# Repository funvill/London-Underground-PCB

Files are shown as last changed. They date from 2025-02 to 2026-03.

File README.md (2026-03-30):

# London-Underground-PCB

A decorative PCB with 600 individually addressable RGB LEDs arranged in the London Underground map layout. Animated trains travel along each tube line using official TfL line colors.

[PCB Preview](https://kicanvas.org/?github=https://github.com/funvill/London-Underground-PCB/tree/main/hardware) via kicanvas

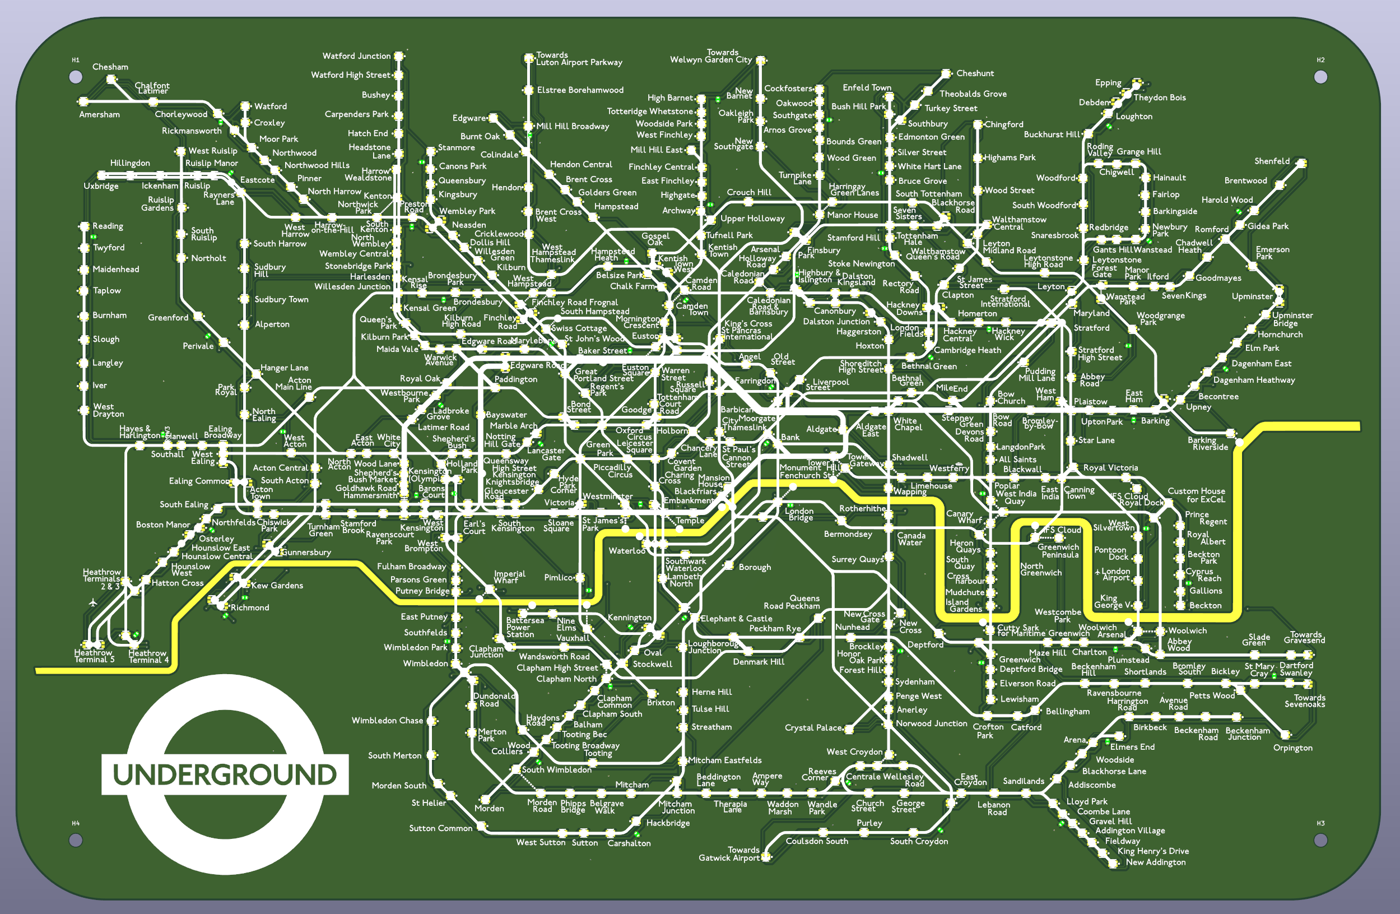
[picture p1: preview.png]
Preview


## Documentation

- [docs.md](docs.md) — Full project documentation (hardware specs, firmware guide, station mapping)
- [CHANGELOG.md](CHANGELOG.md) — Version history for firmware and hardware
- [CLAUDE.md](CLAUDE.md) — Guide for AI assistants making changes to this project

## Versions

- **Hardware:** v2025-Nov-30
- **Firmware:** v1.0.0

## Related

See [Washington Metro PCB](https://github.com/funvill/washington-metro-pcb) for a previous example.

Made by: [Steven (@funvill)](https://blog.abluestar.com/about)

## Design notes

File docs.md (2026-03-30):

# London Underground PCB — Project Documentation

> This document is updated alongside firmware and hardware changes. See [CHANGELOG.md](CHANGELOG.md) for version history.

---

## What is this?

A decorative PCB shaped like the London Underground map with 600 individually addressable RGB LEDs — one per station. The firmware animates "trains" travelling along each tube line in real time, using the correct line colors from the official TfL palette.

The board is powered and controlled by a **Seeed Studio XIAO ESP32C3** microcontroller soldered directly onto the PCB.

Preview

[View PCB in browser (KiCanvas)](https://kicanvas.org/?github=https://github.com/funvill/London-Underground-PCB/tree/main/hardware)

Related project: [Washington Metro PCB](https://github.com/funvill/washington-metro-pcb)

Made by: [Steven (@funvill)](https://blog.abluestar.com/about)

---

## Hardware

### Current Version: v2025-Nov-30

Manufactured by JLCPCB, November 2025.

### Specifications

| Item | Value |
|---|---|
| LEDs | 600× WS2812B (XL-1615RGBC, 1.6×1.5mm) |
| Microcontroller | Seeed Studio XIAO ESP32C3 |
| LED data pin | D7 |
| Power input | USB-C (via XIAO board) |
| LED color order | GRB |
| PCB design tool | KiCAD 7 |

### Components (JLCPCB Part Numbers)

| Component | Description | Part # |
|---|---|---|
| WS2812B LED | 1.6×1.5mm RGB addressable | C5349954 |
| Button | SMD 4-pin 5.1×5.1mm | C318884 |
| Resistor | 0Ω 1206 | C17888 |

### Tube Lines on the Board

| Line | Color (RGB) | Stations |
|---|---|---|
| Bakerloo | (120, 70, 0) brown | 25 |
| Central | Red | 45 |
| Circle | Yellow | 27 |
| District | Green | 49 |
| Hammersmith & City | Pink | 18 |
| Jubilee | White | 27 |
| Metropolitan | Purple | 31 |
| Northern | (50, 50, 50) dark gray | 50 |
| Piccadilly | Blue | 51 |
| Victoria | Light Blue | 16 |
| Waterloo & City | (0, 180, 160) teal | 2 |
| DLR | (0, 220, 140) light green | 38 |
| London Overground | Orange | 15 |
| Elizabeth line | (130, 0, 200) purple | 40 |
| London Trams | (0, 200, 60) green | varies |

### Known Hardware Issues (v2025-Nov-30)

See `Issues with version 2025-Nov-30.txt` for the full list of 31 identified issues. Key items:

**Missing LEDs — stations with no physical LED on this board revision:**
- Bow Road
- Monument
- Barbican
- Cannon Street
- Eastcote
- Euston Square
- High Street Kensington
- South Hampstead
- (plus Iver, Taplow, Maidenhead, Hillingdon, Herne Hill, and others)

**Assembly issues:**
- ESP32C3 pads too small for easy hand-soldering (extend pads 2mm in next revision)
- USB-C cable protrudes past board edge, making flush mounting difficult
- Need more GND test points on back of board
- XIAO pin numbers (e.g. D7) not silkscreened on PCB

**Labeling errors:**
- "Acton Town" label appears on both LED 14 and LED 65
- "Edgware Road" has two different locations (LED 134 vs LED 94)
- LED 101–104 location unknown
- "Colliers Wood" label reversed
- LED 480 is an arrow, not a station
- LED 482 "Gallions" should be "Gallions Reach"; "Cyprus Reach" should be "Cyprus"
- LED 552 labeled "Grants Hill" should be "Wanstead" (labels swapped)

---

## Firmware

### Current Version: v1.0.0

### Building & Flashing

Requirements: [PlatformIO](https://platformio.org/) with the `espressif32` platform.

```bash
cd firmware/Londonmap
pio run                   # compile
pio run --target upload   # flash over USB
pio device monitor        # serial monitor (115200 baud)
```

On boot the board prints:
```
London Underground PCB
https://github.com/funvill/London-Underground-PCB
Lines configured: 15
```

### Current Mode: Test Mode

The firmware currently runs **TestEachLine** mode to help verify the physical LED-to-station mapping. This is active while the mapping in `stations.h` / `lines.h` is being corrected.

Test mode behavior:
1. All stations on the active line illuminate **green**
2. A single **red** LED sweeps from the first station to the last (200 ms per step)
3. After 3 complete passes, the next line becomes active
4. After all 15 lines have been tested, the sequence repeats

Production animation mode (trains moving and fading) is implemented in `main.cpp` but disabled by a `return;` statement. Once the station mappings are verified, remove that `return;` to enable it.

### Source File Overview

| File | Role |
|---|---|
| `version.h` | Version macros — update every change |
| `stations.h` | `const uint16 STATION_NAME = LED_INDEX;` for all 570+ stations |
| `lines.h` | Ordered station sequences per line (`LINE_BAKERLOO[]`, etc.) |
| `line_config.h` | Hardware defines, `LineDef` struct, `kLines[]` table |
| `main.cpp` | `setup()`, `loop()`, test and animation logic |

### Station Mapping

Every station is a named constant in `stations.h`:

```cpp
const uint16 OXFORD_CIRCUS = 230;
const uint16 UNMAPPED_LED  = 0xFFFF;  // station exists but no LED on board
```

Stations that share a physical LED (interchange stations with a single dot on the map) use lettered suffixes:

```cpp
const uint16 BAKER_STREET_A = 116;  // Bakerloo/Jubilee platform
const uint16 BAKER_STREET_B = 117;  // Circle/Metropolitan platform
```

Lines reference these constants in order (direction doesn't matter — trains run both ways):

```cpp
const uint16 LINE_BAKERLOO[] = {
    ELEPHANT_CASTLE_A,
    LAMBETH_NORTH,
    WATERLOO_A,
    // ... 22 more stations ...
    HARROW_WEALDSTONE
};
```

### Adding or Fixing a Station Mapping

1. Edit the `const uint16 STATION_NAME = NEW_INDEX;` line in `stations.h`
2. If the station is on multiple lines, check all references in `lines.h`
3. Bump `VERSION_PATCH` in `version.h`
4. Add a `CHANGELOG.md` entry under `[Unreleased]`

### Adding a New Line

1. Add a `const uint16 LINE_NEW_NAME[]` array to `lines.h`
2. Add a `LineDef` entry to `kLines[]` in `line_config.h` (name, array pointer, color, speed)
3. Bump `VERSION_MINOR` in `version.h`
4. Document in `CHANGELOG.md`

---

## Station Mapping Reference Files

These files in the project root are **first-pass drafts with known errors**:

| File | Description |
|---|---|
| `station-names-to-led.csv` | Station name → LED index (first attempt, needs correction) |
| `stations-to-leds.txt` | Line name → comma-separated LED list (first attempt, needs correction) |

The **authoritative** mapping lives in `firmware/Londonmap/src/stations.h` and `lines.h`. Update those files, not the CSVs/TXTs.

`london_metro_stations_master_list.md` is the canonical list of all TfL stations. Use it as a reference when verifying or correcting mappings.

---

## Design Files

The `design/` folder contains Affinity Designer source files (`.afdesign`) and SVG/PNG exports used to generate the PCB silkscreen graphics. The London Underground map graphic was adapted into the PCB layout.

---

## Repository Files Quick Reference

| File / Folder | Purpose |
|---|---|
| `README.md` | Project intro and links |
| `CLAUDE.md` | AI assistant guide for making changes |
| `docs.md` | This file — full project documentation |
| `CHANGELOG.md` | Version history |
| `firmware/` | PlatformIO firmware source |
| `hardware/` | KiCAD PCB design |
| `design/` | Affinity Designer graphics |
| `preview.png` | Board render |
| `london_metro_stations_master_list.md` | Canonical station list |
| `station-names-to-led.csv` | Draft mapping (WIP, has errors) |
| `stations-to-leds.txt` | Draft line sequences (WIP, has errors) |
| `Issues with version 2025-Nov-30.txt` | Known hardware issues |

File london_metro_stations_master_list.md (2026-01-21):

# London Metro System – Complete Station List

This document lists **all passenger stations** in the London metro system, defined as **all TfL-operated urban rail services**.

**Included**
- London Underground (Tube)
- Docklands Light Railway (DLR)
- London Overground
- Elizabeth line
- London Trams (Tramlink)

**Excluded**
- National Rail–only stations outside TfL branding
- Freight-only or heritage railways

---

## London Underground (Tube)

### Bakerloo Line
- Elephant & Castle
- Lambeth North
- Waterloo
- Embankment
- Charing Cross
- Piccadilly Circus
- Oxford Circus
- Regent’s Park
- Baker Street
- Marylebone
- Edgware Road
- Paddington
- Warwick Avenue
- Maida Vale
- Kilburn Park
- Queen’s Park
- Kensal Green
- Willesden Junction
- Harlesden
- Stonebridge Park
- Wembley Central
- North Wembley
- South Kenton
- Kenton
- Harrow & Wealdstone

### Central Line
- West Ruislip
- Ruislip Gardens
- South Ruislip
- Northolt
- Greenford
- Perivale
- Hanger Lane
- North Acton
- East Acton
- White City
- Shepherd’s Bush
- Holland Park
- Notting Hill Gate
- Queensway
- Lancaster Gate
- Marble Arch
- Bond Street
- Oxford Circus
- Tottenham Court Road
- Holborn
- Chancery Lane
- St Paul’s
- Bank
- Liverpool Street
- Bethnal Green
- Mile End
- Stratford
- Leyton
- Leytonstone
- Wanstead
- Redbridge
- Gants Hill
- Newbury Park
- Barkingside
- Fairlop
- Hainault
- Grange Hill
- Chigwell
- Roding Valley
- Woodford
- Buckhurst Hill
- Loughton
- Debden
- Theydon Bois
- Epping

### Circle Line
- Paddington
- Edgware Road
- Baker Street
- Great Portland Street
- Euston Square
- King’s Cross St Pancras
- Farringdon
- Barbican
- Moorgate
- Liverpool Street
- Aldgate
- Tower Hill
- Monument
- Cannon Street
- Mansion House
- Blackfriars
- Temple
- Embankment
- Westminster
- St James’s Park
- Victoria
- Sloane Square
- South Kensington
- Gloucester Road
- High Street Kensington
- Notting Hill Gate
- Bayswater

### District Line
- Upminster
- Upminster Bridge
- Hornchurch
- Elm Park
- Dagenham East
- Dagenham Heathway
- Becontree
- Upney
- Barking
- East Ham
- Upton Park
- Plaistow
- West Ham
- Bromley-by-Bow
- Bow Road
- Mile End
- Stepney Green
- Whitechapel
- Aldgate East
- Tower Hill
- Monument
- Cannon Street
- Mansion House
- Blackfriars
- Temple
- Embankment
- Westminster
- St James’s Park
- Victoria
- Sloane Square
- South Kensington
- Gloucester Road
- Earl’s Court
- Kensington (Olympia)
- West Brompton
- Fulham Broadway
- Parsons Green
- Putney Bridge
- East Putney
- Southfields
- Wimbledon Park
- Wimbledon
- Turnham Green
- Gunnersbury
- Kew Gardens
- Richmond
- Acton Town
- Ealing Common
- Ealing Broadway

### Hammersmith & City Line
- Hammersmith
- Goldhawk Road
- Shepherd’s Bush Market
- Wood Lane
- Latimer Road
- Ladbroke Grove
- Westbourne Park
- Paddington
- Edgware Road
- Baker Street
- Great Portland Street
- Euston Square
- King’s Cross St Pancras
- Farringdon
- Barbican
- Moorgate
- Liverpool Street
- Whitechapel
- Barking

### Jubilee Line
- Stanmore
- Canons Park
- Queensbury
- Kingsbury
- Wembley Park
- Neasden
- Dollis Hill
- Willesden Green
- Kilburn
- West Hampstead
- Finchley Road
- Swiss Cottage
- St John’s Wood
- Baker Street
- Bond Street
- Green Park
- Westminster
- Waterloo
- Southwark
- London Bridge
- Bermondsey
- Canada Water
- Canary Wharf
- North Greenwich
- Canning Town
- West Ham
- Stratford

### Metropolitan Line
- Aldgate
- Liverpool Street
- Moorgate
- Barbican
- Farringdon
- King’s Cross St Pancras
- Euston Square
- Great Portland Street
- Baker Street
- Finchley Road
- Wembley Park
- Preston Road
- Northwick Park
- Harrow-on-the-Hill
- North Harrow
- Pinner
- Northwood Hills
- Northwood
- Moor Park
- Rickmansworth
- Chorleywood
- Chalfont & Latimer
- Chesham
- Amersham
- Watford
- Croxley
- Uxbridge
- Ickenham
- Ruislip
- Ruislip Manor
- Eastcote
- Rayners Lane

### Northern Line
- Battersea Power Station
- Nine Elms
- Kennington
- Waterloo
- Embankment
- Charing Cross
- Leicester Square
- Tottenham Court Road
- Goodge Street
- Warren Street
- Euston
- Camden Town
- Chalk Farm
- Belsize Park
- Hampstead
- Golders Green
- Brent Cross
- Hendon Central
- Colindale
- Burnt Oak
- Edgware
- Mornington Crescent
- Kentish Town
- Tufnell Park
- Archway
- Highgate
- East Finchley
- Finchley Central
- West Finchley
- Woodside Park
- Totteridge & Whetstone
- High Barnet
- Mill Hill East
- Oval
- Stockwell
- Clapham North
- Clapham Common
- Clapham South
- Balham
- Tooting Bec
- Tooting Broadway
- Colliers Wood
- South Wimbledon
- Morden

### Piccadilly Line
- Cockfosters
- Oakwood
- Southgate
- Arnos Grove
- Bounds Green
- Wood Green
- Turnpike Lane
- Manor House
- Finsbury Park
- Arsenal
- Holloway Road
- Caledonian Road
- King’s Cross St Pancras
- Russell Square
- Holborn
- Covent Garden
- Leicester Square
- Piccadilly Circus
- Green Park
- Hyde Park Corner
- Knightsbridge
- South Kensington
- Gloucester Road
- Earl’s Court
- Barons Court
- Hammersmith
- Acton Town
- South Ealing
- Northfields
- Boston Manor
- Osterley
- Hounslow East
- Hounslow Central
- Hounslow West
- Hatton Cross
- Heathrow Terminals 2 & 3
- Heathrow Terminal 4
- Heathrow Terminal 5
- Ealing Common
- North Ealing
- Park Royal
- Alperton
- Sudbury Town
- Sudbury Hill
- South Harrow
- Rayners Lane
- Eastcote
- Ruislip Manor
- Ruislip
- Ickenham
- Uxbridge

### Victoria Line
- Walthamstow Central
- Blackhorse Road
- Tottenham Hale
- Seven Sisters
- Finsbury Park
- Highbury & Islington
- King’s Cross St Pancras
- Euston
- Warren Street
- Oxford Circus
- Green Park
- Victoria
- Pimlico
- Vauxhall
- Stockwell
- Brixton

### Waterloo & City Line
- Waterloo
- Bank

---

## Docklands Light Railway (DLR)
- Bank
- Tower Gateway
- Shadwell
- Limehouse
- Westferry
- Poplar
- Blackwall
- East India
- Canning Town
- Royal Victoria
- Custom House
- Prince Regent
- Royal Albert
- Beckton Park
- Cyprus
- Gallions Reach
- Beckton
- West Silvertown
- Pontoon Dock
- London City Airport
- King George V
- Woolwich Arsenal
- Stratford
- Stratford International
- Pudding Mill Lane
- Bow Church
- Devons Road
- Langdon Park
- All Saints
- Cutty Sark for Maritime Greenwich
- Greenwich
- Deptford Bridge
- Elverson Road
- Lewisham
- Stratford High Street
- Abbey Road
- West Ham

---

## London Overground
*(Grouped by network; full enumeration retained)*

- Richmond
- Clapham Junction
- Shepherd’s Bush
- Willesden Junction
- Camden Road
- Highbury & Islington
- Stratford
- Barking
- Gospel Oak
- Hackney Central
- Canada Water
- New Cross
- Crystal Palace
- West Croydon
- Watford Junction

---

## Elizabeth line
- Reading
- Twyford
- Maidenhead
- Taplow
- Burnham
- Slough
- Langley
- Iver
- West Drayton
- Hayes & Harlington
- Southall
- Hanwell
- West Ealing
- Ealing Broadway
- Acton Main Line
- Paddington
- Tottenham Court Road
- Farringdon
- Liverpool Street
- Whitechapel
- Canary Wharf
- Custom House
- Woolwich
- Abbey Wood
- Stratford
- Maryland
- Forest Gate
- Manor Park
- Ilford
- Seven Kings
- Goodmayes
- Chadwell Heath
- Romford
- Gidea Park
- Harold Wood
- Brentwood
- Shenfield
- Heathrow Terminals 2 & 3
- Heathrow Terminal 4
- Heathrow Terminal 5

---

## London Trams (Tramlink)
- Wimbledon
- Mitcham Junction
- East Croydon
- West Croydon
- Beckenham Junction
- New Addington
- Elmers End

---

*Document purpose: canonical human-readable reference list. Machine-normalized CSV and NaPTAN-keyed datasets maintained separately.*

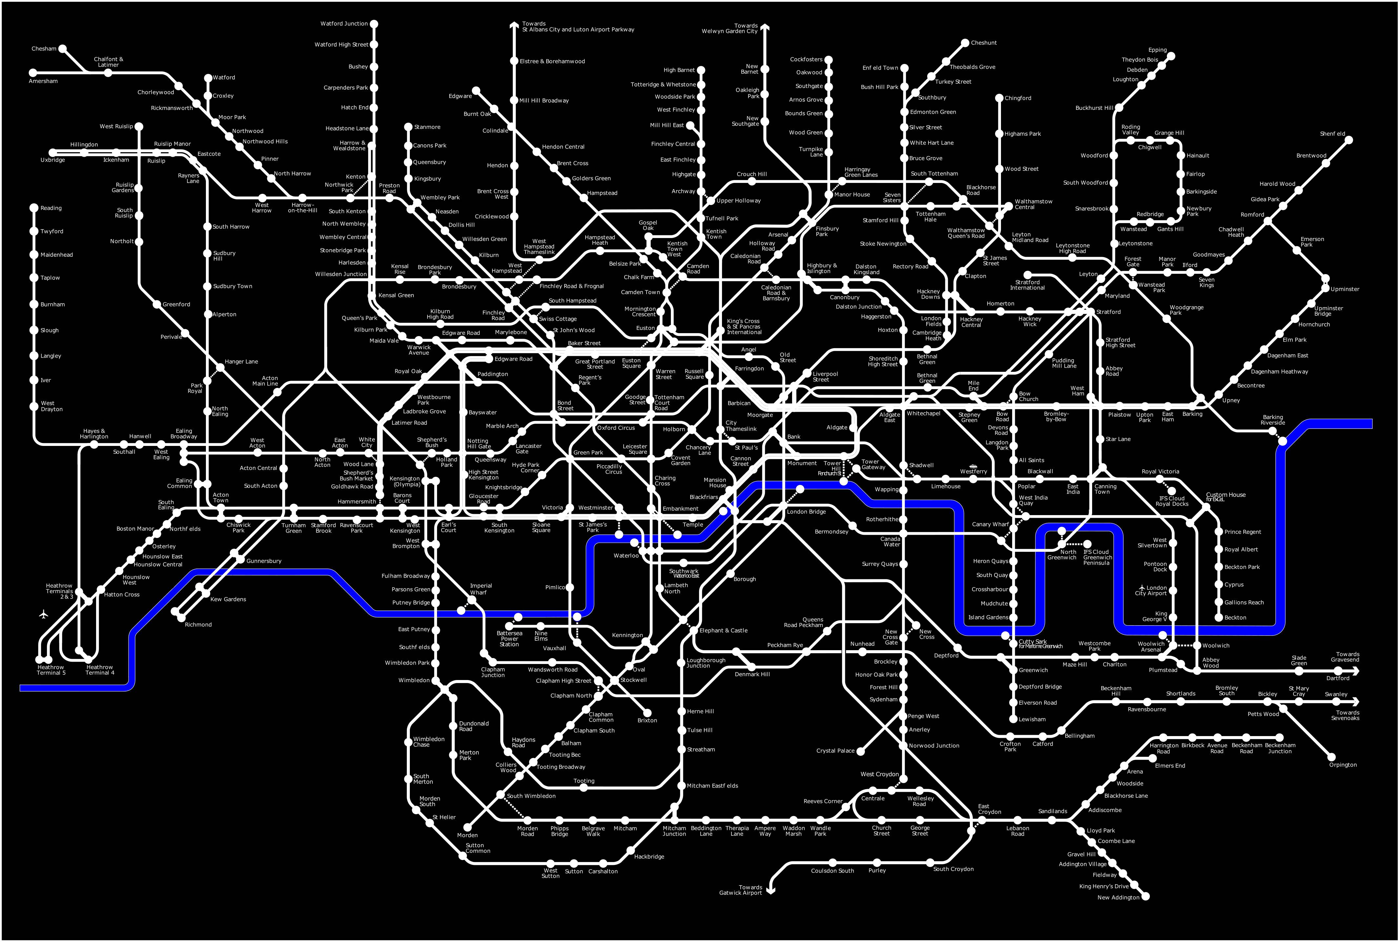
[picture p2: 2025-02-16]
design/london-underground.png

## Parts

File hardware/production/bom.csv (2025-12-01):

Designator | Footprint | Quantity | Value | LCSC Part #
+5V1, +5V2, +5V3, +5V4, +5V5, +5V6, +5V7, +5V8, GND1, LED_IN1, LED_OUT1 | TestPoint_Pad_3.0x3.0mm | 11 | TestPoint
LED1, LED10, LED100, LED101, LED102, LED103, LED104, LED105, LED106, LED107, LED108, LED109, LED11, LED110, LED111, LED112, LED113, LED114, LED115, LED116, LED117, LED118, LED119, LED12, LED120, LED121, LED122, LED123, LED124, LED125, LED126, LED127, LED128, LED129, LED13, LED130, LED131, LED132, LED133, LED134, LED135, LED136, LED137, LED138, LED139, LED14, LED140, LED141, LED142, LED143, LED144, LED145, LED146, LED147, LED148, LED149, LED15, LED150, LED151, LED152, LED153, LED154, LED155, LED156, LED157, LED158, LED159, LED16, LED160, LED161, LED162, LED163, LED164, LED165, LED166, LED167, LED168, LED169, LED17, LED170, LED171, LED172, LED173, LED174, LED175, LED176, LED177, LED178, LED179, LED18, LED180, LED181, LED182, LED183, LED184, LED185, LED186, LED187, LED188, LED189, LED19, LED190, LED191, LED192, LED193, LED194, LED195, LED196, LED197, LED198, LED199, LED2, LED20, LED200, LED201, LED202, LED203, LED204, LED205, LED206, LED207, LED208, LED209, LED21, LED210, LED211, LED212, LED213, LED214, LED215, LED216, LED217, LED218, LED219, LED22, LED220, LED221, LED222, LED223, LED224, LED225, LED226, LED227, LED228, LED229, LED23, LED230, LED231, LED232, LED233, LED234, LED235, LED236, LED237, LED238, LED239, LED24, LED240, LED241, LED242, LED243, LED244, LED245, LED246, LED247, LED248, LED249, LED25, LED250, LED251, LED252, LED253, LED254, LED255, LED256, LED257, LED258, LED259, LED26, LED260, LED261, LED262, LED263, LED264, LED265, LED266, LED267, LED268, LED269, LED27, 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 | LED-SMD_4P-L1.6-W1.5_XL-1615RGBC-WS2812B-1 | 200 | XL-1615RGBC-WS2812B | C5349954
LED28, LED280, LED281, LED282, LED283, LED284, LED285, LED286, LED287, LED288, LED289, LED29, LED290, LED291, LED292, LED293, LED294, LED295, LED296, LED297, LED298, LED299, LED3, LED30, LED300, LED301, LED302, LED303, LED304, LED305, LED306, LED307, LED308, LED309, LED31, LED310, LED311, LED312, LED313, LED314, LED315, LED316, LED317, LED318, LED319, LED32, LED320, LED321, LED322, LED323, LED324, LED325, LED326, LED327, LED328, LED329, LED33, LED330, LED331, LED332, LED333, LED334, LED335, LED336, LED337, LED338, LED339, LED34, LED340, LED341, LED342, LED343, LED344, LED345, LED346, LED347, LED348, LED349, LED35, LED350, LED351, LED352, LED353, LED354, LED355, LED356, LED357, LED358, LED359, LED36, LED360, LED361, LED362, LED363, LED364, LED365, LED366, LED367, LED368, LED369, LED37, LED370, LED371, LED372, LED373, LED374, LED375, LED376, LED377, LED378, LED379, LED38, LED380, LED381, LED382, LED383, LED384, LED385, LED386, LED387, LED388, LED389, LED39, LED390, LED391, LED392, LED393, LED394, LED395, LED396, LED397, LED398, LED399, LED4, LED40, LED400, LED401, LED402, LED403, LED404, LED405, LED406, LED407, LED408, LED409, LED41, LED410, LED411, LED412, LED413, LED414, LED415, LED416, LED417, LED418, LED419, LED42, LED420, LED421, LED422, LED423, LED424, LED425, LED426, LED427, LED428, LED429, LED43, LED430, LED431, LED432, LED433, LED434, LED435, LED436, LED437, LED438, LED439, LED44, LED440, LED441, LED442, LED443, LED444, LED445, LED446, LED447, LED448, LED449, LED45, 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 | LED-SMD_4P-L1.6-W1.5_XL-1615RGBC-WS2812B-1 | 200 | XL-1615RGBC-WS2812B | C5349954
LED46, LED460, LED461, LED462, LED463, LED464, LED465, LED466, LED467, LED468, LED469, LED47, LED470, LED471, LED472, LED473, LED474, LED475, LED476, LED477, LED478, LED479, LED48, LED480, LED481, LED482, LED483, LED484, LED485, LED486, LED487, LED488, LED489, LED49, LED490, LED491, LED492, LED493, LED494, LED495, LED496, LED497, LED498, LED499, LED5, LED50, LED500, LED501, LED502, LED503, LED504, LED505, LED506, LED507, LED508, LED509, LED51, LED510, LED511, LED512, LED513, LED514, LED515, LED516, LED517, LED518, LED519, LED52, LED520, LED521, LED522, LED523, LED524, LED525, LED526, LED527, LED528, LED529, LED53, LED530, LED531, LED532, LED533, LED534, LED535, LED536, LED537, LED538, LED539, LED54, LED540, LED541, LED542, LED543, LED544, LED545, LED546, LED547, LED548, LED549, LED55, LED550, LED551, LED552, LED553, LED554, LED555, LED556, LED557, LED558, LED559, LED56, LED560, LED561, LED562, LED563, LED564, LED565, LED566, LED567, LED568, LED569, LED57, LED58, LED59, LED6, LED60, LED61, LED62, LED63, LED64, LED65, LED66, LED67, LED68, LED69, LED7, LED70, LED71, LED72, LED73, LED74, LED75, LED76, LED77, LED78, LED79, LED8, LED80, LED81, LED82, LED83, LED84, LED85, LED86, LED87, LED88, LED89, LED9, LED90, LED91, LED92, LED93, LED94, LED95, LED96, LED97, LED98, LED99 | LED-SMD_4P-L1.6-W1.5_XL-1615RGBC-WS2812B-1 | 169 | XL-1615RGBC-WS2812B | C5349954
R1, R2, R3, R4, R5, R6 | 1206 | 6 | 1206W4F0000T5E | C17888
ROW1, ROW10, ROW11, ROW12, ROW13, ROW14, ROW15, ROW16, ROW17, ROW18, ROW19, ROW2, ROW20, ROW21, ROW22, ROW23, ROW24, ROW25, ROW26, ROW27, ROW28, ROW29, ROW3, ROW30, ROW31, ROW32, ROW33, ROW34, ROW35, ROW36, ROW37, ROW38, ROW39, ROW4, ROW40, ROW41, ROW42, ROW43, ROW44, ROW45, ROW46, ROW47, ROW48, ROW49, ROW5, ROW50, ROW51, ROW52, ROW53, ROW54, ROW55, ROW56, ROW57, ROW58, ROW59, ROW6, ROW60, ROW7, ROW8, ROW9 | 0402 | 60 | 10uF,10V,X5R | C52923

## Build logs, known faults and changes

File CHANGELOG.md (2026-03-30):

# Changelog

All notable changes to this project will be documented here.

Firmware versions follow [Semantic Versioning](https://semver.org/): `MAJOR.MINOR.PATCH`
- MAJOR: incompatible changes (e.g. pin reassignment, LED count change)
- MINOR: new features (e.g. new animation mode, new line added)
- PATCH: bug fixes (e.g. corrected station-to-LED mapping)

Hardware versions use the date format `YYYY-Mon-DD`.

---

## [Unreleased]

---

## Firmware v1.3.3 — 2026-03-30

**TEST mode: pause and quit controls.**

- Feature: Press `SPACE` while in TEST mode to toggle pause/resume. LEDs hold their current state while paused, making it easy to read and copy serial output. Console prints `[PAUSED]` / `[RESUMED]`.
- Feature: Press `Q` while in TEST mode to quit immediately and return to RUN mode. Console prints `[TEST mode ended] Returning to RUN mode.`
- Both keys are processed immediately (not line-buffered), so no Enter key is needed.
- Updated `printHelp()` to document both keys.

---

## Firmware v1.3.2 — 2026-03-29

**Bug fixes.**

- Fix: Added `Serial.setTxTimeoutMs(0)` after `Serial.begin()` to prevent device freeze when USB is connected for power only (no serial host). ESP32C3 USB-CDC blocked indefinitely on TX queue without this.
- Fix: Removed duplicate `NOTTING_HILL_GATE` from `LINE_CENTRAL_A` in `lines.h`. `NOTTING_HILL_GATE` and `LANCASTER_GATE` both map to LED 230 (same physical PCB LED). Having both in the array caused LED 230 to appear at two non-adjacent steps. Correct Central line order is now `QUEENSWAY (229) → LANCASTER_GATE (230)`.

---

## Firmware v1.3.1 — 2026-03-29

**Diagnostic improvements: TEST mode serial logging and new audit commands.**

- Added `tools/generate_station_names.py` — reads `stations.h` and generates
  `firmware/Londonmap/src/station_names.h`: a 552-entry sorted lookup table
  mapping LED strip indices to station constant names and human-readable names.
- TEST mode now prints a serial log line for every step:
  `[TrackName (#N)]  step X/Y  LED:NNN  CONST_NAME  "Human Name"`
- TEST mode slowed to 500 ms/step (was 200 ms) and 2 loops per line (was 3)
  so the console log is readable in real time.
- Current station marker changed from pure red to orange-red (255,80,0)
  for better contrast against green background.
- New command `TEST <name>` — jump directly to a specific named line in TEST mode.
- New command `LINES` — list all configured line names, indices and station counts.
- New command `TRACKINFO <name>` — dump every station in a line with LED index,
  constant name, and human-readable name.
- New command `WHICH <N>` — show which lines and offsets reference a given LED index.
- New command `REPORT <track> <offset> <actual_led>` — user reports that at a given
  offset in a track, a different LED lit up; firmware prints a comparison and a
  suggested `lines.h` fix (e.g. `Change LINE_CENTRAL_A[5] from EAST_ACTON to ...`).
- Updated `printHelp()` to reflect all new commands.
- Build: SUCCESS — 21.9% Flash, 5.0% RAM.

---

## Firmware v1.3.0 — 2026-03-29

**Comprehensive line definitions rewrite (Phase 5): branch splitting and route corrections.**

- Added `FARRINGDON = UNMAPPED_LED` to `stations.h` (was omitted; no physical LED on board)
- Rewrote `lines.h` completely — all lines with multiple destinations are now split into
  named variants (A/B/C) rather than a single mangled array:
  - `LINE_CENTRAL_A/B/C` — main trunk + Ealing Broadway branch + Hainault loop
  - `LINE_CIRCLE` — now the complete 27-station clockwise loop (previously truncated)
  - `LINE_DISTRICT_A/B/C` — main trunk (Upminster→Wimbledon) + Richmond branch + Ealing Broadway branch
  - `LINE_HAMMERSMITH_AND_CITY` — FARRINGDON now included (UNMAPPED_LED)
  - `LINE_METROPOLITAN_A/B/C` — main trunk (Aldgate→Amersham) + Chesham spur + Watford branch;
    Uxbridge/Ruislip/Eastcote/Rayners Lane removed (Piccadilly-only since 2003)
  - `LINE_NORTHERN_A/B/C` — Charing Cross branch (Morden→Edgware) + Bank branch
    (Battersea→High Barnet, now includes BOROUGH/LONDON_BRIDGE/OLD_STREET/ANGEL) + Mill Hill East spur
  - `LINE_PICCADILLY_A/B/C` — main trunk (Cockfosters→Heathrow T5) + Terminal 4 loop + Uxbridge branch
  - `LINE_DLR_A/B/C/D` — Beckton trunk + Woolwich Arsenal branch + Stratford→Lewisham + Stratford High St spur
  - `LINE_OVERGROUND_A/B/C/D` — Mildmay (NLL) + Windrush (ELL) + Suffragette (Gospel Oak→Barking) + Lioness (Watford)
  - `LINE_ELIZABETH_A/B` — main trunk (Reading→Shenfield) + Heathrow branch
  - `LINE_TRAMS_A/B/C` — New Addington branch + Beckenham Junction branch + Elmers End branch
- Updated `kLines[]` in `line_config.h` — 36 entries (up from 15), one per route variant
- Build: SUCCESS — 19.7% Flash, 5.0% RAM

---

## Firmware v1.2.0 — 2026-03-29

**Corrected station-to-LED mapping (Phase 4).**

- Fixed root bug: `stations.h` previously stored 1-based KiCAD reference numbers
  (e.g. `ACTON_TOWN_A = 14` meaning LED14) instead of 0-based strip indices
  (correct: `ACTON_TOWN_A = 13`, the 14th LED at strip position 13)
- All 559 station constants updated to 0-based indices via `tools/generate_stations_h.py`
- 11 stations remain `UNMAPPED_LED` (no physical LED on this board version):
  Barbican, Bow Road, Cannon Street, Eastcote, Euston Square, High Street
  Kensington, Monument, New Barnet, South Hampstead, and 2 others
- Station mapping sourced from `tools/led_map_verified.csv` (webcam-verified positions)
- Added `tools/generate_stations_h.py`: regenerates `stations.h` from verified CSV;
  handles suffix constants (`_A`/`_B`/`_C`/`_D`), shared-LED aliases, manual overrides,
  and fuzzy name matching between C++ constants and CSV labels
- Added `tools/stations_h_report.txt`: change log produced by the generator

---

## Firmware v1.1.0 — 2026-03-29

**Serial control + RUN mode default.**

- Default boot mode is now `RUN` (fading train animation) instead of `TestEachLine`
- Added mode state machine: `enum Mode { RUN, TEST, SERIAL_CONTROL }`
- Added serial command set (115200 baud, newline-terminated):
  - `L <N>` — light LED index N in white
  - `S` — sequential scan, LED 0 to NUM_LEDS-1, 500 ms each
  - `T <N>` — show all stations on line index N in that line's color
  - `TRACK <NAME>` — same as `T` but addressed by line name (case-insensitive)
  - `RUN` — switch to production fading-train animation
  - `TEST` — switch to `TestEachLine` mode
  - `C` — clear all LEDs
  - `I` — print firmware version, line count, NUM_LEDS, current mode
  - `B <0-255>` — set brightness
- Firmware version and command list printed to serial on boot
- Added `#include <version.h>` to `main.cpp`

---

## Hardware v2025-Nov-30

**PCB manufactured by JLCPCB.**

- 600 WS2812B LEDs arranged in London Underground map layout
- Seeed Studio XIAO ESP32C3 microcontroller
- USB-C power input via ESP32C3 board

**Known issues (31 total — see `Issues with version 2025-Nov-30.txt`):**
- 9 stations have no LED on the board (Bow Road, Monument, Barbican, Cannon Street, Eastcote, Euston Square, High Street Kensington, South Hampstead, and others)
- 9 LED positions on board are unlabeled or unknown
- ESP32C3 pads too small for easy hand-soldering; USB-C cable protrudes past board edge
- Several silkscreen labels incorrect or misplaced

---

## Firmware v1.0.0 — 2026-03-29

**Initial versioned release. Corresponds to hardware v2025-Nov-30 test phase.**

- Added `version.h` with `VERSION_MAJOR`, `VERSION_MINOR`, `VERSION_PATCH`, `VERSION_STRING`
- Firmware currently runs `TestEachLine()` mode: cycles through each tube line, illuminates all stations green with a red LED moving station-by-station
- Supports 15 tube lines: Bakerloo, Central, Circle, District, H&C, Jubilee, Metropolitan, Northern, Piccadilly, Victoria, Waterloo & City, DLR, Overground, Elizabeth, Trams
- Station-to-LED mapping in `stations.h`; line sequences in `lines.h`
- 9 stations assigned `UNMAPPED_LED` (0xFFFF) pending hardware fix
- Production animation (moving trains with fade) implemented but disabled pending LED mapping verification

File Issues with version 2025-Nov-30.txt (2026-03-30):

# Issues with version 2025-Nov-30

- ESP32 and the USB cable to too close to the edge of the board, The cable sticks out the bottom and makes it hard to mount
- The pads on the ESP32 are too small for easy soldering, extend them out at lest 2 more mm 

- Add more GND pads to the back of the board 
- Add seeed_xiao board pin numbers. D7
- Is not in the list of Stations C:\Users\funvill\Documents\git\London-Underground-PCB\station-names-to-led.csv
  - Iver (LED24)
  - Taplow (LED28)
  - Maidenhead (LED29)
  - Hillingdon (LED33)
  - Herne Hill (LED197)
  - Towards Luton Airport Parkway (LED264)
  - West Croydon (LED302)
  - Towards Gatwick Airport (LED308)
  - Towards Sevenoaks (LED459)

- There are two LEDs with the same name "Action Town" LED65, LED14
- "Edgware Road" has two different locations. 134, 94
- LED 101-104 where are these?
- South Kenton lable is misleading, it looks like it is apart of different led.
- "Edgware Road" mulitple locations
- "Colliers Wood" should be "Wood Colliers" label is backwards, LED181
- The "Oxford Circus" lable is offset
- "Tower Hill" lable is miss labled
- near LED471, there is a lable that should be there "Greenwich"
- LED480 shouldn't be here, its a arrow.
- LED482 "Gallions" should be "Gallions Reach", and "Cyprus Reach" should be "Cyprus"
- LED552 Should be "Wanstead" instead of "Grants Hill". these labels are reversed.
- LED470 "IFS Cloud Greenwich Peninsula" label is bad. 
- LED469 "North greenwich" label is in the wrong spot

- "Hounslow East" station is missing an LED
- "Bow Road" station is missing an LED
- "Monument" (D6) station is missing an LED
- "Barbican" (C5) station is missing an LED
- "Bow Road" (C7) station is missing an LED
- "Cannon Street" (D5) station is missing an LED
- "Eastcote" (B2) station is missing an LED
- "Euston Square" (B5) station is missing an LED
- "High Street Kensington" (D3) station is missing an LED
- "South Hampstead" (C3) station is missing an LED

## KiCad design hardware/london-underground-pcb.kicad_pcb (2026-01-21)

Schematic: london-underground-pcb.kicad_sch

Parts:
+5V1, +5V2, +5V3, +5V4, +5V5, +5V6, +5V7, +5V8: TestPoint; TestPoint_Pad_3.0x3.0mm
GND1: TestPoint; TestPoint_Pad_3.0x3.0mm
H1, H2, H3, H4: MountingHole; MountingHole_3.2mm_M3_DIN965_Pad
LED1, LED2, LED3, LED4, LED5, LED6, LED7, LED8, LED9, LED10, LED11, LED12, LED13, LED14, LED15, LED16, LED17, LED18, LED19, LED20, LED21, LED22, LED23, LED24, LED25, LED26, LED27, LED28, LED29, LED30, LED31, LED32, LED33, LED34, LED35, LED36, LED37, LED38, LED39, LED40, LED41, LED42, LED43, LED44, LED45, LED46, LED47, LED48, LED49, LED50, LED51, LED52, LED53, LED54, LED55, LED56, LED57, LED58, LED59, LED60, LED61, LED62, LED63, LED64, LED65, LED66, LED67, LED68, LED69, LED70, LED71, LED72, LED73, LED74, LED75, LED76, LED77, LED78, LED79, LED80, LED81, LED82, LED83, LED84, LED85, LED86, LED87, LED88, LED89, LED90, LED91, LED92, LED93, LED94, LED95, LED96, LED97, LED98, LED99, LED100, LED101, LED102, LED103, LED104, LED105, LED106, LED107, LED108, LED109, LED110, LED111, LED112, LED113, LED114, LED115, LED116, LED117, LED118, LED119, LED120, LED121, LED122, LED123, LED124, LED125, LED126, LED127, LED128, LED129, LED130, LED131, LED132, LED133, LED134, LED135, LED136, LED137, LED138, LED139, LED140, LED141, LED142, LED143, LED144, LED145, LED146, LED147, LED148, LED149, LED150, LED151, LED152, LED153, LED154, LED155, LED156, LED157, LED158, LED159, LED160, LED161, LED162, LED163, LED164, LED165, LED166, LED167, LED168, LED169, LED170, LED171, LED172, LED173, LED174, LED175, LED176, LED177, LED178, LED179, LED180, LED181, LED182, LED183, LED184, LED185, LED186, LED187, LED188, LED189, LED190, LED191, LED192, LED193, LED194, LED195, LED196, LED197, LED198, LED199, LED200, LED201, LED202, LED203, LED204, LED205, LED206, LED207, LED208, LED209, LED210, LED211, LED212, LED213, LED214, LED215, LED216, LED217, LED218, LED219, LED220, LED221, LED222, LED223, LED224, LED225, LED226, LED227, LED228, LED229, LED230, LED231, LED232, LED233, LED234, LED235, LED236, LED237, LED238, LED239, LED240, LED241, LED242, LED243, LED244, LED245, LED246, LED247, LED248, LED249, LED250, LED251, LED252, LED253, LED254, LED255, LED256, LED257, LED258, LED259, LED260, LED261, LED262, LED263, LED264, LED265, LED266, LED267, LED268, LED269, LED270, LED271, LED272, LED273, LED274, LED275, LED276, LED277, LED278, LED279, LED280, LED281, LED282, LED283, LED284, LED285, LED286, LED287, LED288, LED289, LED290, LED291, LED292, LED293, LED294, LED295, LED296, LED297, LED298, LED299, LED300, LED301, LED302, LED303, LED304, LED305, LED306, LED307, LED308, LED309, LED310, LED311, LED312, LED313, LED314, LED315, LED316, LED317, LED318, LED319, LED320, LED321, LED322, LED323, LED324, LED325, LED326, LED327, LED328, LED329, LED330, LED331, LED332, LED333, LED334, LED335, LED336, LED337, LED338, LED339, LED340, LED341, LED342, LED343, LED344, LED345, LED346, LED347, LED348, LED349, LED350, LED351, LED352, LED353, LED354, LED355, LED356, LED357, LED358, LED359, LED360, LED361, LED362, LED363, LED364, LED365, LED366, LED367, LED368, LED369, LED370, LED371, LED372, LED373, LED374, LED375, LED376, LED377, LED378, LED379, LED380, LED381, LED382, LED383, LED384, LED385, LED386, LED387, LED388, LED389, LED390, LED391, LED392, LED393, LED394, LED395, LED396, LED397, LED398, LED399, LED400, LED401, LED402, LED403, LED404, LED405, LED406, LED407, LED408, LED409, LED410, LED411, LED412, LED413, LED414, LED415, LED416, LED417, LED418, LED419, LED420, LED421, LED422, LED423, LED424, LED425, LED426, LED427, LED428, LED429, LED430, LED431, LED432, LED433, LED434, LED435, LED436, LED437, LED438, LED439, LED440, LED441, LED442, LED443, LED444, LED445, LED446, LED447, LED448, LED449, LED450, LED451, LED452, LED453, LED454, LED455, LED456, LED457, LED458, LED459, LED460, LED461, LED462, LED463, LED464, LED465, LED466, LED467, LED468, LED469, LED470, LED471, LED472, LED473, LED474, LED475, LED476, LED477, LED478, LED479, LED480, LED481, LED482, LED483, LED484, LED485, LED486, LED487, LED488, LED489, LED490, LED491, LED492, LED493, LED494, LED495, LED496, LED497, LED498, LED499, LED500, LED501, LED502, LED503, LED504, LED505, LED506, LED507, LED508, LED509, LED510, LED511, LED512, LED513, LED514, LED515, LED516, LED517, LED518, LED519, LED520, LED521, LED522, LED523, LED524, LED525, LED526, LED527, LED528, LED529, LED530, LED531, LED532, LED533, LED534, LED535, LED536, LED537, LED538, LED539, LED540, LED541, LED542, LED543, LED544, LED545, LED546, LED547, LED548, LED549, LED550, LED551, LED552, LED553, LED554, LED555, LED556, LED557, LED558, LED559, LED560, LED561, LED562, LED563, LED564, LED565, LED566, LED567, LED568, LED569: XL-1615RGBC-WS2812B; LED-SMD_4P-L1.6-W1.5_XL-1615RGBC-WS2812B-1; LCSC Part C5349954
LED_IN1: TestPoint; TestPoint_Pad_3.0x3.0mm
LED_OUT1: TestPoint; TestPoint_Pad_3.0x3.0mm
R1, R2, R3, R4, R5, R6: 1206W4F0000T5E; R_1206_3216Metric; LCSC Part C17888
ROW1, ROW2, ROW3, ROW4, ROW5, ROW6, ROW7, ROW8, ROW9, ROW10, ROW11, ROW12, ROW13, ROW14, ROW15, ROW16, ROW17, ROW18, ROW19, ROW20, ROW21, ROW22, ROW23, ROW24, ROW25, ROW26, ROW27, ROW28, ROW29, ROW30, ROW31, ROW32, ROW33, ROW34, ROW35, ROW36, ROW37, ROW38, ROW39, ROW40, ROW41, ROW42, ROW43, ROW44, ROW45, ROW46, ROW47, ROW48, ROW49, ROW50, ROW51, ROW52, ROW53, ROW54, ROW55, ROW56, ROW57, ROW58, ROW59, ROW60: 10uF,10V,X5R; C_0402_1005Metric; MFGPN CL05A105KA5NQNC; LCSC C52923
SW1, SW2, SW3, SW4: TS-1187A-B-A-B; SW-SMD_4P-L5.1-W5.1-P3.70-LS6.5-TL_H1.5; LCSC Part C318884; not fitted
U1: XIAO-RP2040-DIP; XIAO-RP2040-SMD; not fitted

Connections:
+5V: +5V1.1, +5V2.1, +5V3.1, +5V4.1, +5V5.1, +5V6.1, +5V7.1, +5V8.1, LED1.3 (VDD), LED2.3 (VDD), LED3.3 (VDD), LED4.3 (VDD), LED5.3 (VDD), LED6.3 (VDD), LED7.3 (VDD), LED8.3 (VDD), LED9.3 (VDD), LED10.3 (VDD), LED11.3 (VDD), LED12.3 (VDD), LED13.3 (VDD), LED14.3 (VDD), LED15.3 (VDD), LED16.3 (VDD), LED17.3 (VDD), LED18.3 (VDD), LED19.3 (VDD), LED20.3 (VDD), LED21.3 (VDD), LED22.3 (VDD), LED23.3 (VDD), LED24.3 (VDD), LED25.3 (VDD), LED26.3 (VDD), LED27.3 (VDD), LED28.3 (VDD), LED29.3 (VDD), LED30.3 (VDD), LED31.3 (VDD), LED32.3 (VDD), LED33.3 (VDD), LED34.3 (VDD), LED35.3 (VDD), LED36.3 (VDD), LED37.3 (VDD), LED38.3 (VDD), LED39.3 (VDD), LED40.3 (VDD), LED41.3 (VDD), LED42.3 (VDD), LED43.3 (VDD), LED44.3 (VDD), LED45.3 (VDD), LED46.3 (VDD), LED47.3 (VDD), LED48.3 (VDD), LED49.3 (VDD), LED50.3 (VDD), LED51.3 (VDD), LED52.3 (VDD), LED53.3 (VDD), LED54.3 (VDD), LED55.3 (VDD), LED56.3 (VDD), LED57.3 (VDD), LED58.3 (VDD), LED59.3 (VDD), LED60.3 (VDD), LED61.3 (VDD), LED62.3 (VDD), LED63.3 (VDD), LED64.3 (VDD), LED65.3 (VDD), LED66.3 (VDD), LED67.3 (VDD), LED68.3 (VDD), LED69.3 (VDD), LED70.3 (VDD), LED71.3 (VDD), LED72.3 (VDD), LED73.3 (VDD), LED74.3 (VDD), LED75.3 (VDD), LED76.3 (VDD), LED77.3 (VDD), LED78.3 (VDD), LED79.3 (VDD), LED80.3 (VDD), LED81.3 (VDD), LED82.3 (VDD), LED83.3 (VDD), LED84.3 (VDD), LED85.3 (VDD), LED86.3 (VDD), LED87.3 (VDD), LED88.3 (VDD), LED89.3 (VDD), LED90.3 (VDD), LED91.3 (VDD), LED92.3 (VDD), LED93.3 (VDD), LED94.3 (VDD), LED95.3 (VDD), LED96.3 (VDD), LED97.3 (VDD), LED98.3 (VDD), LED99.3 (VDD), LED100.3 (VDD), LED101.3 (VDD), LED102.3 (VDD), LED103.3 (VDD), LED104.3 (VDD), LED105.3 (VDD), LED106.3 (VDD), LED107.3 (VDD), LED108.3 (VDD), LED109.3 (VDD), LED110.3 (VDD), LED111.3 (VDD), LED112.3 (VDD), LED113.3 (VDD), LED114.3 (VDD), LED115.3 (VDD), LED116.3 (VDD), LED117.3 (VDD), LED118.3 (VDD), LED119.3 (VDD), LED120.3 (VDD), LED121.3 (VDD), LED122.3 (VDD), LED123.3 (VDD), LED124.3 (VDD), LED125.3 (VDD), LED126.3 (VDD), LED127.3 (VDD), LED128.3 (VDD), LED129.3 (VDD), LED130.3 (VDD), LED131.3 (VDD), LED132.3 (VDD), LED133.3 (VDD), LED134.3 (VDD), LED135.3 (VDD), LED136.3 (VDD), LED137.3 (VDD), LED138.3 (VDD), LED139.3 (VDD), LED140.3 (VDD), LED141.3 (VDD), LED142.3 (VDD), LED143.3 (VDD), LED144.3 (VDD), LED145.3 (VDD), LED146.3 (VDD), LED147.3 (VDD), LED148.3 (VDD), LED149.3 (VDD), LED150.3 (VDD), LED151.3 (VDD), LED152.3 (VDD), LED153.3 (VDD), LED154.3 (VDD), LED155.3 (VDD), LED156.3 (VDD), LED157.3 (VDD), LED158.3 (VDD), LED159.3 (VDD), LED160.3 (VDD), LED161.3 (VDD), LED162.3 (VDD), LED163.3 (VDD), LED164.3 (VDD), LED165.3 (VDD), LED166.3 (VDD), LED167.3 (VDD), LED168.3 (VDD), LED169.3 (VDD), LED170.3 (VDD), LED171.3 (VDD), LED172.3 (VDD), LED173.3 (VDD), LED174.3 (VDD), LED175.3 (VDD), LED176.3 (VDD), LED177.3 (VDD), LED178.3 (VDD), LED179.3 (VDD), LED180.3 (VDD), LED181.3 (VDD), LED182.3 (VDD), LED183.3 (VDD), LED184.3 (VDD), LED185.3 (VDD), LED186.3 (VDD), LED187.3 (VDD), LED188.3 (VDD), LED189.3 (VDD), LED190.3 (VDD), LED191.3 (VDD), LED192.3 (VDD), LED193.3 (VDD), LED194.3 (VDD), LED195.3 (VDD), LED196.3 (VDD), LED197.3 (VDD), LED198.3 (VDD), LED199.3 (VDD), LED200.3 (VDD), LED201.3 (VDD), LED202.3 (VDD), LED203.3 (VDD), LED204.3 (VDD), LED205.3 (VDD), LED206.3 (VDD), LED207.3 (VDD), LED208.3 (VDD), LED209.3 (VDD), LED210.3 (VDD), LED211.3 (VDD), LED212.3 (VDD), LED213.3 (VDD), LED214.3 (VDD), LED215.3 (VDD), LED216.3 (VDD), LED217.3 (VDD), LED218.3 (VDD), LED219.3 (VDD), LED220.3 (VDD), LED221.3 (VDD), LED222.3 (VDD), LED223.3 (VDD), LED224.3 (VDD), LED225.3 (VDD), LED226.3 (VDD), LED227.3 (VDD), LED228.3 (VDD), LED229.3 (VDD), LED230.3 (VDD), LED231.3 (VDD), LED232.3 (VDD), LED233.3 (VDD), LED234.3 (VDD), LED235.3 (VDD), LED236.3 (VDD), LED237.3 (VDD), LED238.3 (VDD), LED239.3 (VDD), LED240.3 (VDD), LED241.3 (VDD), LED242.3 (VDD), LED243.3 (VDD), LED244.3 (VDD), LED245.3 (VDD), LED246.3 (VDD), LED247.3 (VDD), LED248.3 (VDD), LED249.3 (VDD), LED250.3 (VDD), LED251.3 (VDD), LED252.3 (VDD), LED253.3 (VDD), LED254.3 (VDD), LED255.3 (VDD), LED256.3 (VDD), LED257.3 (VDD), LED258.3 (VDD), LED259.3 (VDD), LED260.3 (VDD), LED261.3 (VDD), LED262.3 (VDD), LED263.3 (VDD), LED264.3 (VDD), LED265.3 (VDD), LED266.3 (VDD), LED267.3 (VDD), LED268.3 (VDD), LED269.3 (VDD), LED270.3 (VDD), LED271.3 (VDD), LED272.3 (VDD), LED273.3 (VDD), LED274.3 (VDD), LED275.3 (VDD), LED276.3 (VDD), LED277.3 (VDD), LED278.3 (VDD), LED279.3 (VDD), LED280.3 (VDD), LED281.3 (VDD), LED282.3 (VDD), LED283.3 (VDD), LED284.3 (VDD), LED285.3 (VDD), LED286.3 (VDD), LED287.3 (VDD), LED288.3 (VDD), LED289.3 (VDD), LED290.3 (VDD), LED291.3 (VDD), LED292.3 (VDD), LED293.3 (VDD), LED294.3 (VDD), LED295.3 (VDD), LED296.3 (VDD), LED297.3 (VDD), LED298.3 (VDD), LED299.3 (VDD), LED300.3 (VDD), LED301.3 (VDD), LED302.3 (VDD), LED303.3 (VDD), LED304.3 (VDD), LED305.3 (VDD), LED306.3 (VDD), LED307.3 (VDD), LED308.3 (VDD), LED309.3 (VDD), LED310.3 (VDD), LED311.3 (VDD), LED312.3 (VDD), LED313.3 (VDD), LED314.3 (VDD), LED315.3 (VDD), LED316.3 (VDD), LED317.3 (VDD), LED318.3 (VDD), LED319.3 (VDD), LED320.3 (VDD), LED321.3 (VDD), LED322.3 (VDD), LED323.3 (VDD), LED324.3 (VDD), LED325.3 (VDD), LED326.3 (VDD), LED327.3 (VDD), LED328.3 (VDD), LED329.3 (VDD), LED330.3 (VDD), LED331.3 (VDD), LED332.3 (VDD), LED333.3 (VDD), LED334.3 (VDD), LED335.3 (VDD), LED336.3 (VDD), LED337.3 (VDD), LED338.3 (VDD), LED339.3 (VDD), LED340.3 (VDD), LED341.3 (VDD), LED342.3 (VDD), LED343.3 (VDD), LED344.3 (VDD), LED345.3 (VDD), LED346.3 (VDD), LED347.3 (VDD), LED348.3 (VDD), LED349.3 (VDD), LED350.3 (VDD), LED351.3 (VDD), LED352.3 (VDD), LED353.3 (VDD), LED354.3 (VDD), LED355.3 (VDD), LED356.3 (VDD), LED357.3 (VDD), LED358.3 (VDD), LED359.3 (VDD), LED360.3 (VDD), LED361.3 (VDD), LED362.3 (VDD), LED363.3 (VDD), LED364.3 (VDD), LED365.3 (VDD), LED366.3 (VDD), LED367.3 (VDD), LED368.3 (VDD), LED369.3 (VDD), LED370.3 (VDD), LED371.3 (VDD), LED372.3 (VDD), LED373.3 (VDD), LED374.3 (VDD), LED375.3 (VDD), LED376.3 (VDD), LED377.3 (VDD), LED378.3 (VDD), LED379.3 (VDD), LED380.3 (VDD), LED381.3 (VDD), LED382.3 (VDD), LED383.3 (VDD), LED384.3 (VDD), LED385.3 (VDD), LED386.3 (VDD), LED387.3 (VDD), LED388.3 (VDD), LED389.3 (VDD), LED390.3 (VDD), LED391.3 (VDD), LED392.3 (VDD), LED393.3 (VDD), LED394.3 (VDD), LED395.3 (VDD), LED396.3 (VDD), LED397.3 (VDD), LED398.3 (VDD), LED399.3 (VDD), LED400.3 (VDD), LED401.3 (VDD), LED402.3 (VDD), LED403.3 (VDD), LED404.3 (VDD), LED405.3 (VDD), LED406.3 (VDD), LED407.3 (VDD), LED408.3 (VDD), LED409.3 (VDD), LED410.3 (VDD), LED411.3 (VDD), LED412.3 (VDD), LED413.3 (VDD), LED414.3 (VDD), LED415.3 (VDD), LED416.3 (VDD), LED417.3 (VDD), LED418.3 (VDD), LED419.3 (VDD), LED420.3 (VDD), LED421.3 (VDD), LED422.3 (VDD), LED423.3 (VDD)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
BUTTON_01: SW1.1 (A), U1.1 (GPIO26/ADC0/A0)
BUTTON_02: SW3.1 (A), U1.2 (GPIO27/ADC1/A1)
BUTTON_03: SW2.2 (B), U1.3 (GPIO28/ADC2/A2)
BUTTON_04: SW4.2 (B), U1.4 (GPIO29/ADC3/A3)
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

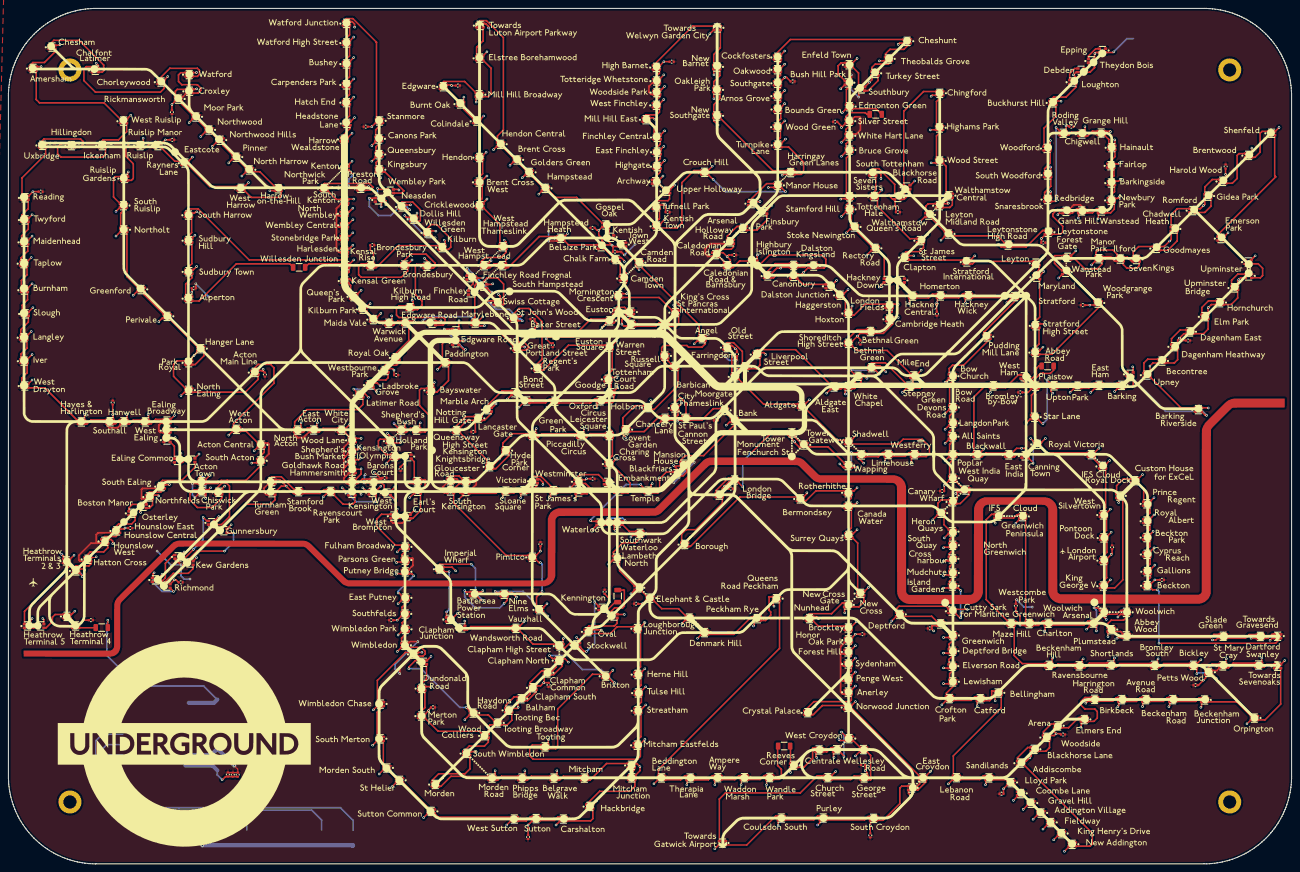
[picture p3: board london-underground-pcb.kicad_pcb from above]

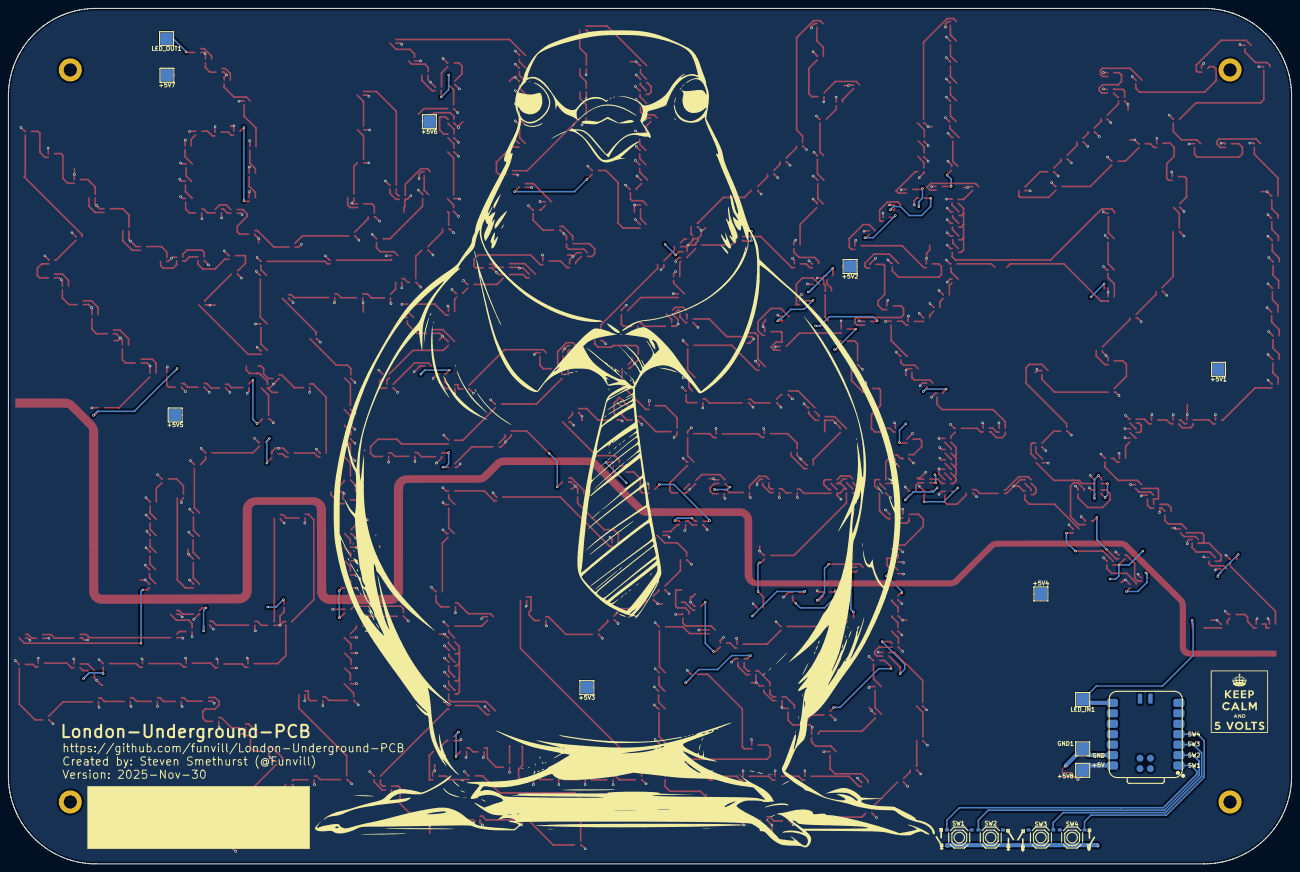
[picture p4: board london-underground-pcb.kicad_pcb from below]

Board: 2 copper layers, 312.0 x 208.0 mm, 655 parts (16 on the bottom side), 582 nets.

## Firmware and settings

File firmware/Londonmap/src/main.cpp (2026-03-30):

#include <Arduino.h>
#include <FastLED.h>

#include <line_config.h>
#include <station_names.h>
#include <stations.h>
#include <version.h>

CRGB leds[NUM_LEDS];

static_assert(LINE_COUNT > 0, "kLines[] must contain at least one line");

// ---------------------------------------------------------------------------
// Mode state machine
// ---------------------------------------------------------------------------

enum Mode { RUN, TEST, SERIAL_CONTROL };
static Mode g_mode = RUN;

// ---------------------------------------------------------------------------
// Train animation state
// ---------------------------------------------------------------------------

static int16_t g_trainOffset[LINE_COUNT][TRAIN_COUNT];
static uint32_t g_lastMoveMs[LINE_COUNT];
static uint32_t g_lastFadeMs = 0;

void SetTrainStartingPositions()
{
  for (size_t lineIndex = 0; lineIndex < LINE_COUNT; lineIndex++)
  {
    const uint16_t stationCount = kLines[lineIndex].stationCount;
    for (uint8_t trainIndex = 0; trainIndex < TRAIN_COUNT; trainIndex++)
    {
      const uint16_t spacing = (TRAIN_COUNT == 0) ? 0 : static_cast<uint16_t>(stationCount / TRAIN_COUNT);
      g_trainOffset[lineIndex][trainIndex] = static_cast<int16_t>(spacing * trainIndex);
    }
    g_lastMoveMs[lineIndex] = 0;
  }
}

void ProgressDemoTrain(const size_t lineIndex)
{
  const uint16_t stationCount = kLines[lineIndex].stationCount;
  if (stationCount == 0)
  {
    return;
  }

  for (uint8_t trainIndex = 0; trainIndex < TRAIN_COUNT; trainIndex++)
  {
    // Even trains move forwards, odd trains move backwards.
    if ((trainIndex % 2) == 0)
    {
      g_trainOffset[lineIndex][trainIndex]++;
    }
    else
    {
      g_trainOffset[lineIndex][trainIndex]--;
    }

    if (g_trainOffset[lineIndex][trainIndex] >= static_cast<int16_t>(stationCount))
    {
      g_trainOffset[lineIndex][trainIndex] = 0;
    }
    else if (g_trainOffset[lineIndex][trainIndex] < 0)
    {
      g_trainOffset[lineIndex][trainIndex] = static_cast<int16_t>(stationCount - 1);
    }
  }
}

void DrawTrains()
{
  for (size_t lineIndex = 0; lineIndex < LINE_COUNT; lineIndex++)
  {
    const LineDef &line = kLines[lineIndex];
    if (line.stationCount == 0)
    {
      continue;
    }

    for (uint8_t trainIndex = 0; trainIndex < TRAIN_COUNT; trainIndex++)
    {
      const uint16_t stationIndex = static_cast<uint16_t>(g_trainOffset[lineIndex][trainIndex]);
      const uint16 ledIndex = line.stations[stationIndex];

      if (ledIndex != UNMAPPED_LED && ledIndex < NUM_LEDS)
      {
        leds[ledIndex] = line.color;
      }
    }
  }
}

// ---------------------------------------------------------------------------
// Test mode — cycles through lines with green overlay and red position marker
// ---------------------------------------------------------------------------

static size_t   g_testLineIndex    = 0;
static uint16_t g_testStationIndex = 0;
static uint16_t g_testLoopCount    = 0;
static uint32_t g_lastTestMoveMs   = 0;
static bool     g_testPaused       = false;

// Print a single-line serial summary for the current test step.
// Format:  [LineName (lineIdx)] step/total  LED:NNN  CONST_NAME  "Human Name"
static void printTestStep(size_t lineIdx, uint16_t step)
{
  const LineDef &line = kLines[lineIdx];
  const uint16_t ledIndex = line.stations[step];

  // [Central-A (#1)] step  3/35
  Serial.print('[');
  Serial.print(line.name);
  Serial.print(" (#");
  Serial.print(static_cast<uint32_t>(lineIdx));
  Serial.print(")]  step ");
  if (step < 10)  Serial.print(' ');
  if (step < 100) Serial.print(' ');
  Serial.print(static_cast<uint32_t>(step));
  Serial.print('/');
  Serial.print(static_cast<uint32_t>(line.stationCount - 1));

  // LED index (or UNMAPPED)
  Serial.print("  LED:");
  if (ledIndex == UNMAPPED_LED)
  {
    Serial.print("UNMAPPED");
  }
  else
  {
    if (ledIndex < 100) Serial.print(' ');
    if (ledIndex < 10)  Serial.print(' ');
    Serial.print(static_cast<uint32_t>(ledIndex));
  }

  // Station names from lookup table
  if (ledIndex != UNMAPPED_LED)
  {
    const StationNameEntry *e = findStationEntry(ledIndex);
    if (e)
    {
      Serial.print("  ");
      Serial.print(e->constName);
      Serial.print("  \"");
      Serial.print(e->humanName);
      Serial.print('"');
    }
  }
  Serial.println();
}

void TestEachLine(const uint32_t now, const uint16_t timeLedMoveMs, const uint16_t loopsPerTrainLine)
{
  if (g_testPaused)
  {
    return; // paused — LEDs stay as-is until space is pressed again
  }
  if ((now - g_lastTestMoveMs) < timeLedMoveMs)
  {
    return;
  }
  g_lastTestMoveMs = now;

  fill_solid(leds, NUM_LEDS, CRGB::Black);

  const LineDef &line = kLines[g_testLineIndex];

  // All stations on current line → green
  for (uint16_t i = 0; i < line.stationCount; i++)
  {
    const uint16_t ledIndex = line.stations[i];
    if (ledIndex != UNMAPPED_LED && ledIndex < NUM_LEDS)
    {
      leds[ledIndex] = CRGB::Green;
    }
  }

  // Current station → bright red (yellow tint so it reads through green)
  if (g_testStationIndex < line.stationCount)
  {
    const uint16_t ledIndex = line.stations[g_testStationIndex];
    if (ledIndex != UNMAPPED_LED && ledIndex < NUM_LEDS)
    {
      leds[ledIndex] = CRGB(255, 80, 0); // vivid orange-red, distinct from green
    }
  }

  FastLED.show();

  // Serial log for this step
  printTestStep(g_testLineIndex, g_testStationIndex);

  g_testStationIndex++;
  if (g_testStationIndex >= line.stationCount)
  {
    g_testStationIndex = 0;
    g_testLoopCount++;

    if (g_testLoopCount >= loopsPerTrainLine)
    {
      g_testLoopCount = 0;
      g_testLineIndex = (g_testLineIndex + 1) % LINE_COUNT;

      // Announce the next line
      Serial.println();
      Serial.print("--- ");
      Serial.print(kLines[g_testLineIndex].name);
      Serial.print(" (#");
      Serial.print(static_cast<uint32_t>(g_testLineIndex));
      Serial.print(") --- ");
      Serial.print(static_cast<uint32_t>(kLines[g_testLineIndex].stationCount));
      Serial.println(" stations");
    }
    else
    {
      Serial.print("  >> loop ");
      Serial.print(static_cast<uint32_t>(g_testLoopCount + 1));
      Serial.print('/');
      Serial.println(static_cast<uint32_t>(loopsPerTrainLine));
    }
  }
}

// ---------------------------------------------------------------------------
// Serial command handling
// ---------------------------------------------------------------------------

static String g_serialBuf;

void printHelp()
{
  Serial.println("Commands:");
  Serial.println("  L <N>                   Light LED N in white");
  Serial.println("  LC <N> <R> <G> <B>      Light LED N with RGB color");
  Serial.println("  S                       Sequential scan (500ms each)");
  Serial.println("  T <N>                   Show line index N in its color");
  Serial.println("  TRACK <NAME>            Show named line (e.g. TRACK Central-A)");
  Serial.println("  RUN                     Fading-train animation");
  Serial.println("  TEST                    Step through all lines (500ms, 2 loops each)");
  Serial.println("  TEST <NAME>             Step through a specific named line");
  Serial.println("  SPACE                   (in TEST mode) Toggle pause/resume");
  Serial.println("  Q                       (in TEST mode) Quit test and return to RUN");
  Serial.println("  TRACKINFO <NAME>        Dump station list for a line");
  Serial.println("  LINES                   List all configured line names and indices");
  Serial.println("  WHICH <N>               Show which lines reference LED N");
  Serial.println("  REPORT <NAME> <OFF> <N> Report wrong LED: track, offset, actual LED seen");
  Serial.println("  C                       Clear all LEDs");
  Serial.println("  I                       Print firmware info");
  Serial.println("  B <0-255>               Set brightness");
}

// Find line index by name (case-insensitive). Returns -1 if not found.
static int findLineByName(const String &name)
{
  for (size_t i = 0; i < LINE_COUNT; i++)
  {
    if (String(kLines[i].name).equalsIgnoreCase(name))
    {
      return static_cast<int>(i);
    }
  }
  return -1;
}

static void cmdShowLine(int idx)
{
  fill_solid(leds, NUM_LEDS, CRGB::Black);
  const LineDef &line = kLines[idx];
  for (uint16_t i = 0; i < line.stationCount; i++)
  {
    const uint16_t ledIndex = line.stations[i];
    if (ledIndex != UNMAPPED_LED && ledIndex < NUM_LEDS)
    {
      leds[ledIndex] = line.color;
    }
  }
  FastLED.show();
  Serial.print("Line ");
  Serial.print(idx);
  Serial.print(": ");
  Serial.println(line.name);
}

void handleSerialCommand(const String &cmd)
{
  String trimmed = cmd;
  trimmed.trim();
  if (trimmed.length() == 0)
  {
    return;
  }

  // --- RUN ---
  if (trimmed.equalsIgnoreCase("RUN"))
  {
    g_mode = RUN;
    SetTrainStartingPositions();
    Serial.println("Mode: RUN");
    return;
  }

  // --- TEST [optional name] ---
  if (trimmed.equalsIgnoreCase("TEST") ||
      (trimmed.length() > 5 && trimmed.substring(0, 5).equalsIgnoreCase("TEST ")))
  {
    g_mode = TEST;
    g_testStationIndex = 0;
    g_testLoopCount    = 0;
    g_lastTestMoveMs   = 0;

    if (trimmed.length() > 5)
    {
      // TEST <NAME> — jump to a specific named line
      const String name = trimmed.substring(5);
      const int idx = findLineByName(name);
      if (idx < 0)
      {
        Serial.print("Error: unknown line '");
        Serial.print(name);
        Serial.println("'");
        g_mode = SERIAL_CONTROL;
        return;
      }
      g_testLineIndex = static_cast<size_t>(idx);
    }
    else
    {
      g_testLineIndex = 0;
    }

    Serial.println("Mode: TEST (500ms step, 2 loops per line)");
    Serial.print("--- ");
    Serial.print(kLines[g_testLineIndex].name);
    Serial.print(" (#");
    Serial.print(static_cast<uint32_t>(g_testLineIndex));
    Serial.print(") --- ");
    Serial.print(static_cast<uint32_t>(kLines[g_testLineIndex].stationCount));
    Serial.println(" stations");
    return;
  }

  // --- C (clear) ---
  if (trimmed.equalsIgnoreCase("C"))
  {
    g_mode = SERIAL_CONTROL;
    fill_solid(leds, NUM_LEDS, CRGB::Black);
    FastLED.show();
    Serial.println("Cleared");
    return;
  }

  // --- I (info) ---
  if (trimmed.equalsIgnoreCase("I"))
  {
    Serial.print("Firmware: ");
    Serial.println(VERSION_STRING);
    Serial.print("Lines:    ");
    Serial.println(static_cast<uint32_t>(LINE_COUNT));
    Serial.print("NUM_LEDS: ");
    Serial.println(static_cast<uint32_t>(NUM_LEDS));
    Serial.print("Mode:     ");
    if      (g_mode == RUN)            Serial.println("RUN");
    else if (g_mode == TEST)           Serial.println("TEST");
    else                               Serial.println("SERIAL_CONTROL");
    return;
  }

  // --- S (sequential scan) ---
  if (trimmed.equalsIgnoreCase("S"))
  {
    g_mode = SERIAL_CONTROL;
    Serial.print("Scanning ");
    Serial.print(NUM_LEDS);
    Serial.println(" LEDs (500ms each)...");
    for (uint16_t i = 0; i < NUM_LEDS; i++)
    {
      fill_solid(leds, NUM_LEDS, CRGB::Black);
      leds[i] = CRGB::White;
      FastLED.show();
      Serial.print("LED ");
      Serial.println(i);
      delay(500);
    }
    fill_solid(leds, NUM_LEDS, CRGB::Black);
    FastLED.show();
    Serial.println("Scan complete");
    return;
  }

  // --- LC <N> <R> <G> <B> ---
  if (trimmed.length() >= 7 && (trimmed[0] == 'L' || trimmed[0] == 'l') &&
      (trimmed[1] == 'C' || trimmed[1] == 'c') && trimmed[2] == ' ')
  {
    // Parse: LC <N> <R> <G> <B>
    const String rest = trimmed.substring(3);
    int sp1 = rest.indexOf(' ');
    int sp2 = (sp1 >= 0) ? rest.indexOf(' ', sp1 + 1) : -1;
    int sp3 = (sp2 >= 0) ? rest.indexOf(' ', sp2 + 1) : -1;
    if (sp1 < 0 || sp2 < 0 || sp3 < 0)
    {
      Serial.println("Error: LC usage: LC <N> <R> <G> <B>");
      return;
    }
    const int n = rest.substring(0, sp1).toInt();
    const int r = rest.substring(sp1 + 1, sp2).toInt();
    const int g = rest.substring(sp2 + 1, sp3).toInt();
    const int b = rest.substring(sp3 + 1).toInt();
    if (n < 0 || n >= static_cast<int>(NUM_LEDS) ||
        r < 0 || r > 255 || g < 0 || g > 255 || b < 0 || b > 255)
    {
      Serial.println("Error: LC index or color value out of range");
      return;
    }
    g_mode = SERIAL_CONTROL;
    fill_solid(leds, NUM_LEDS, CRGB::Black);
    leds[n] = CRGB(r, g, b);
    FastLED.show();
    Serial.print("LC ");
    Serial.print(n);
    Serial.print(" ");
    Serial.print(r);
    Serial.print(" ");
    Serial.print(g);
    Serial.print(" ");
    Serial.println(b);
    return;
  }

  // --- L <N> ---
  if (trimmed.length() >= 3 && (trimmed[0] == 'L' || trimmed[0] == 'l') && trimmed[1] == ' ')
  {
    const int n = trimmed.substring(2).toInt();
    if (n >= 0 && n < static_cast<int>(NUM_LEDS))
    {
      g_mode = SERIAL_CONTROL;
      fill_solid(leds, NUM_LEDS, CRGB::Black);
      leds[n] = CRGB::White;
      FastLED.show();
      Serial.print("LED ");
      Serial.println(n);
    }
    else
    {
      Serial.print("Error: index out of range (0-");
      Serial.print(NUM_LEDS - 1);
      Serial.println(")");
    }
    return;
  }

  // --- T <N> ---
  if (trimmed.length() >= 3 && (trimmed[0] == 'T' || trimmed[0] == 't') && trimmed[1] == ' ')
  {
    const int n = trimmed.substring(2).toInt();
    if (n >= 0 && n < static_cast<int>(LINE_COUNT))
    {
      g_mode = SERIAL_CONTROL;
      cmdShowLine(n);
    }
    else
    {
      Serial.print("Error: line index out of range (0-");
      Serial.print(LINE_COUNT - 1);
      Serial.println(")");
    }
    return;
  }

  // --- TRACK <NAME> ---
  if (trimmed.length() > 6 && trimmed.substring(0, 6).equalsIgnoreCase("TRACK "))
  {
    const String name = trimmed.substring(6);
    const int idx = findLineByName(name);
    if (idx >= 0)
    {
      g_mode = SERIAL_CONTROL;
      cmdShowLine(idx);
    }
    else
    {
      Serial.print("Error: unknown line '");
      Serial.print(name);
      Serial.println("'");
    }
    return;
  }

  // --- B <0-255> ---
  if (trimmed.length() >= 3 && (trimmed[0] == 'B' || trimmed[0] == 'b') && trimmed[1] == ' ')
  {
    const int val = trimmed.substring(2).toInt();
    if (val >= 0 && val <= 255)
    {
      FastLED.setBrightness(static_cast<uint8_t>(val));
      FastLED.show();
      Serial.print("Brightness: ");
      Serial.println(val);
    }
    else
    {
      Serial.println("Error: brightness out of range (0-255)");
    }
    return;
  }

  // --- LINES ---
  if (trimmed.equalsIgnoreCase("LINES"))
  {
    Serial.print("Configured lines (");
    Serial.print(static_cast<uint32_t>(LINE_COUNT));
    Serial.println(")");
    for (size_t i = 0; i < LINE_COUNT; i++)
    {
      Serial.print("  #");
      if (i < 10) Serial.print(' ');
      Serial.print(static_cast<uint32_t>(i));
      Serial.print("  ");
      Serial.print(kLines[i].name);
      Serial.print("  (");
      Serial.print(static_cast<uint32_t>(kLines[i].stationCount));
      Serial.println(" stations)");
    }
    return;
  }

  // --- TRACKINFO <NAME> ---
  if (trimmed.length() > 10 && trimmed.substring(0, 10).equalsIgnoreCase("TRACKINFO "))
  {
    const String name = trimmed.substring(10);
    const int idx = findLineByName(name);
    if (idx < 0)
    {
      Serial.print("Error: unknown line '");
      Serial.print(name);
      Serial.println("'. Use LINES to list all.");
      return;
    }
    const LineDef &line = kLines[idx];
    Serial.print("Track: ");
    Serial.print(line.name);
    Serial.print(" (#");
    Serial.print(idx);
    Serial.print(") — ");
    Serial.print(static_cast<uint32_t>(line.stationCount));
    Serial.println(" stations");
    for (uint16_t i = 0; i < line.stationCount; i++)
    {
      const uint16_t ledIndex = line.stations[i];
      Serial.print("  [");
      if (i < 10)  Serial.print(' ');
      if (i < 100) Serial.print(' ');
      Serial.print(static_cast<uint32_t>(i));
      Serial.print("]  LED:");
      if (ledIndex == UNMAPPED_LED)
      {
        Serial.print("UNMAPPED");
      }
      else
      {
        if (ledIndex < 100) Serial.print(' ');
        if (ledIndex < 10)  Serial.print(' ');
        Serial.print(static_cast<uint32_t>(ledIndex));
        const StationNameEntry *e = findStationEntry(ledIndex);
        if (e)
        {
          Serial.print("  ");
          Serial.print(e->constName);
          Serial.print("  \"");
          Serial.print(e->humanName);
          Serial.print('"');
        }
      }
      Serial.println();
    }
    return;
  }

  // --- WHICH <N> ---
  if (trimmed.length() >= 7 && trimmed.substring(0, 6).equalsIgnoreCase("WHICH "))
  {
    const int targetLed = trimmed.substring(6).toInt();
    if (targetLed < 0 || targetLed >= static_cast<int>(NUM_LEDS))
    {
      Serial.print("Error: LED index out of range (0-");
      Serial.print(NUM_LEDS - 1);
      Serial.println(")");
      return;
    }
    const uint16_t led = static_cast<uint16_t>(targetLed);
    Serial.print("LED ");
    Serial.print(static_cast<uint32_t>(led));
    const StationNameEntry *e = findStationEntry(led);
    if (e)
    {
      Serial.print("  ");
      Serial.print(e->constName);
      Serial.print("  \"");
      Serial.print(e->humanName);
      Serial.print('"');
    }
    Serial.println("  found in:");
    bool found = false;
    for (size_t i = 0; i < LINE_COUNT; i++)
    {
      const LineDef &line = kLines[i];
      for (uint16_t j = 0; j < line.stationCount; j++)
      {
        if (line.stations[j] == led)
        {
          Serial.print("    ");
          Serial.print(line.name);
          Serial.print(" (#");
          Serial.print(static_cast<uint32_t>(i));
          Serial.print(") offset ");
          Serial.println(static_cast<uint32_t>(j));
          found = true;
        }
      }
    }
    if (!found) Serial.println("    (not used in any line)");
    return;
  }

  // --- REPORT <NAME> <OFFSET> <ACTUAL_LED> ---
  // User reports: at <OFFSET> in line <NAME>, LED <ACTUAL_LED> lit instead of expected.
  // Firmware prints a comparison and the suggested lines.h fix.
  if (trimmed.length() > 7 && trimmed.substring(0, 7).equalsIgnoreCase("REPORT "))
  {
    // Parse three tokens after "REPORT "
    const String rest = trimmed.substring(7);
    const int sp1 = rest.indexOf(' ');
    const int sp2 = (sp1 >= 0) ? rest.indexOf(' ', sp1 + 1) : -1;
    if (sp1 < 0 || sp2 < 0)
    {
      Serial.println("Usage: REPORT <track_name> <offset> <actual_led_index>");
      Serial.println("  Example: REPORT Central-A 5 72");
      return;
    }
    const String trackName  = rest.substring(0, sp1);
    const int    offset     = rest.substring(sp1 + 1, sp2).toInt();
    const int    actualLed  = rest.substring(sp2 + 1).toInt();

    const int lineIdx = findLineByName(trackName);
    if (lineIdx < 0)
    {
      Serial.print("Error: unknown line '");
      Serial.print(trackName);
      Serial.println("'");
      return;
    }
    const LineDef &line = kLines[lineIdx];
    if (offset < 0 || offset >= static_cast<int>(line.stationCount))
    {
      Serial.print("Error: offset out of range (0-");
      Serial.print(line.stationCount - 1);
      Serial.println(")");
      return;
    }
    if (actualLed < 0 || actualLed >= static_cast<int>(NUM_LEDS))
    {
      Serial.print("Error: actual LED index out of range (0-");
      Serial.print(NUM_LEDS - 1);
      Serial.println(")");
      return;
    }

    const uint16_t expectedLed = line.stations[offset];
    const uint16_t reportedLed = static_cast<uint16_t>(actualLed);

    Serial.println("----- REPORT -----");
    Serial.print("Track   : ");
    Serial.print(line.name);
    Serial.print(" (#");
    Serial.print(lineIdx);
    Serial.print(")  offset ");
    Serial.print(static_cast<uint32_t>(offset));
    Serial.print('/');
    Serial.println(line.stationCount - 1);

    // Expected (configured)
    Serial.print("Expected: LED ");
    if (expectedLed == UNMAPPED_LED)
    {
      Serial.print("UNMAPPED");
    }
    else
    {
      Serial.print(static_cast<uint32_t>(expectedLed));
      const StationNameEntry *e = findStationEntry(expectedLed);
      if (e)
      {
        Serial.print("  ");
        Serial.print(e->constName);
        Serial.print("  \"");
        Serial.print(e->humanName);
        Serial.print('"');
      }
    }
    Serial.println();

    // Reported (actual)
    Serial.print("Reported: LED ");
    Serial.print(static_cast<uint32_t>(reportedLed));
    {
      const StationNameEntry *e = findStationEntry(reportedLed);
      if (e)
      {
        Serial.print("  ");
        Serial.print(e->constName);
        Serial.print("  \"");
        Serial.print(e->humanName);
        Serial.print('"');
      }
    }
    Serial.println();
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
void loop()
{
  const uint32_t now = millis();

  checkSerial();

  if (g_mode == RUN)
  {
    // Move trains (each line advances independently)
    for (size_t lineIndex = 0; lineIndex < LINE_COUNT; lineIndex++)
    {
      const uint16_t interval = kLines[lineIndex].moveEveryMs;
      if ((now - g_lastMoveMs[lineIndex]) >= interval)
      {
        g_lastMoveMs[lineIndex] = now;
        ProgressDemoTrain(lineIndex);
      }
    }

    // Fade + draw + show
    if ((now - g_lastFadeMs) >= FADE_INTERVAL_MS)
    {
      g_lastFadeMs = now;
      fadeToBlackBy(leds, NUM_LEDS, FADE_AMOUNT);
      DrawTrains();
      FastLED.show();
    }
  }
  else if (g_mode == TEST)
  {
    const uint16_t TIME_LED_MOVE          = 500;  // 500 ms per station — readable on console
    const uint16_t LOOPS_PER_TRAIN_LINE   = 2;    // 2 passes per line then advance
    TestEachLine(now, TIME_LED_MOVE, LOOPS_PER_TRAIN_LINE);
  }
  // SERIAL_CONTROL: LEDs are set directly by commands; nothing to do in loop.
}

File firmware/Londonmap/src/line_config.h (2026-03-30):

#pragma once

#include <Arduino.h>
#include <FastLED.h>

#include <lines.h>

// -----------------------------------------------------------------------------
// Hardware / animation settings
// -----------------------------------------------------------------------------

// FastLED non-type template parameters are simplest as macros.
#define DATA_PIN D7
#define LED_TYPE WS2811
#define COLOR_ORDER GRB

// LEDs on the strip.
constexpr uint16_t NUM_LEDS = 600;

// Demo behavior.
constexpr uint8_t TRAIN_COUNT = 1;
constexpr uint32_t SERIAL_BAUD = 115200;
constexpr uint8_t BRIGHTNESS = 33; // 32 = 7% 
constexpr uint16_t FADE_INTERVAL_MS = 20;
constexpr uint8_t FADE_AMOUNT = 10;

struct LineDef
{
  const char *name;
  const uint16 *stations;
  uint16_t stationCount;
  CRGB color;
  uint16_t moveEveryMs;
};

template <size_t N>
constexpr uint16_t CountOf(const uint16 (&)[N])
{
  static_assert(N <= 65535, "Line too long");
  return static_cast<uint16_t>(N);
}

// Add/remove lines here. The animation engine in main.cpp is data-driven.
// Colors are simple approximations; adjust to taste.
constexpr uint16_t BASE_TRAIN_PROGRESS_SPEED_MS = 1500;

// clang-format off
constexpr LineDef kLines[] = {
    // Bakerloo — single trunk, brown
    {"Bakerloo",    LINE_BAKERLOO,          CountOf(LINE_BAKERLOO),          CRGB(120, 70, 0),   static_cast<uint16_t>(BASE_TRAIN_PROGRESS_SPEED_MS + 120)},

    // Central — three segments, red
    {"Central-A",   LINE_CENTRAL_A,         CountOf(LINE_CENTRAL_A),         CRGB::Red,          static_cast<uint16_t>(BASE_TRAIN_PROGRESS_SPEED_MS + 180)},
    {"Central-B",   LINE_CENTRAL_B,         CountOf(LINE_CENTRAL_B),         CRGB::Red,          static_cast<uint16_t>(BASE_TRAIN_PROGRESS_SPEED_MS + 180)},
    {"Central-C",   LINE_CENTRAL_C,         CountOf(LINE_CENTRAL_C),         CRGB::Red,          static_cast<uint16_t>(BASE_TRAIN_PROGRESS_SPEED_MS + 180)},

    // Circle — complete loop, yellow
    {"Circle",      LINE_CIRCLE,            CountOf(LINE_CIRCLE),            CRGB::Yellow,       static_cast<uint16_t>(BASE_TRAIN_PROGRESS_SPEED_MS + 260)},

    // District — three branches, green
    {"District-A",  LINE_DISTRICT_A,        CountOf(LINE_DISTRICT_A),        CRGB(0, 150, 0),    static_cast<uint16_t>(BASE_TRAIN_PROGRESS_SPEED_MS + 220)},
    {"District-B",  LINE_DISTRICT_B,        CountOf(LINE_DISTRICT_B),        CRGB(0, 150, 0),    static_cast<uint16_t>(BASE_TRAIN_PROGRESS_SPEED_MS + 220)},
    {"District-C",  LINE_DISTRICT_C,        CountOf(LINE_DISTRICT_C),        CRGB(0, 150, 0),    static_cast<uint16_t>(BASE_TRAIN_PROGRESS_SPEED_MS + 220)},

    // Hammersmith & City — single trunk, pink
    {"H&C",         LINE_HAMMERSMITH_AND_CITY, CountOf(LINE_HAMMERSMITH_AND_CITY), CRGB(220, 90, 150), static_cast<uint16_t>(BASE_TRAIN_PROGRESS_SPEED_MS + 310)},

    // Jubilee — single trunk, silver/white
    {"Jubilee",     LINE_JUBILEE,           CountOf(LINE_JUBILEE),           CRGB(160, 160, 160),static_cast<uint16_t>(BASE_TRAIN_PROGRESS_SPEED_MS + 150)},

    // Metropolitan — three segments, purple
    {"Met-A",       LINE_METROPOLITAN_A,    CountOf(LINE_METROPOLITAN_A),    CRGB(130, 0, 180),  static_cast<uint16_t>(BASE_TRAIN_PROGRESS_SPEED_MS + 210)},
    {"Met-B",       LINE_METROPOLITAN_B,    CountOf(LINE_METROPOLITAN_B),    CRGB(130, 0, 180),  static_cast<uint16_t>(BASE_TRAIN_PROGRESS_SPEED_MS + 210)},
    {"Met-C",       LINE_METROPOLITAN_C,    CountOf(LINE_METROPOLITAN_C),    CRGB(130, 0, 180),  static_cast<uint16_t>(BASE_TRAIN_PROGRESS_SPEED_MS + 210)},

    // Northern — three segments, near-black/dark grey
    {"Northern-A",  LINE_NORTHERN_A,        CountOf(LINE_NORTHERN_A),        CRGB(50, 50, 50),   static_cast<uint16_t>(BASE_TRAIN_PROGRESS_SPEED_MS + 330)},
    {"Northern-B",  LINE_NORTHERN_B,        CountOf(LINE_NORTHERN_B),        CRGB(50, 50, 50),   static_cast<uint16_t>(BASE_TRAIN_PROGRESS_SPEED_MS + 330)},
    {"Northern-C",  LINE_NORTHERN_C,        CountOf(LINE_NORTHERN_C),        CRGB(50, 50, 50),   static_cast<uint16_t>(BASE_TRAIN_PROGRESS_SPEED_MS + 330)},

    // Piccadilly — three segments, dark blue
    {"Picca-A",     LINE_PICCADILLY_A,      CountOf(LINE_PICCADILLY_A),      CRGB(0, 0, 200),    static_cast<uint16_t>(BASE_TRAIN_PROGRESS_SPEED_MS + 190)},
    {"Picca-B",     LINE_PICCADILLY_B,      CountOf(LINE_PICCADILLY_B),      CRGB(0, 0, 200),    static_cast<uint16_t>(BASE_TRAIN_PROGRESS_SPEED_MS + 190)},
    {"Picca-C",     LINE_PICCADILLY_C,      CountOf(LINE_PICCADILLY_C),      CRGB(0, 0, 200),    static_cast<uint16_t>(BASE_TRAIN_PROGRESS_SPEED_MS + 190)},

    // Victoria — single trunk, light blue
    {"Victoria",    LINE_VICTORIA,          CountOf(LINE_VICTORIA),          CRGB(0, 160, 220),  static_cast<uint16_t>(BASE_TRAIN_PROGRESS_SPEED_MS + 140)},

    // Waterloo & City — single trunk, teal
    {"W&C",         LINE_WATERLOO_AND_CITY, CountOf(LINE_WATERLOO_AND_CITY), CRGB(0, 180, 160),  static_cast<uint16_t>(BASE_TRAIN_PROGRESS_SPEED_MS + 80)},
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

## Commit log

2025-02-16 WIP: Getting the font size correct
    [london-underground-pcb.kicad_sch]
2025-02-18 Updated the silkscreen in the PCB with larger font
2025-02-18 first 150 LEDS placed
    [london-underground-pcb.kicad_sch]
2025-02-18 Placed 570 LEDS,
    Still need to do the routing
    [london-underground-pcb.kicad_sch]
2025-02-21 Resolving DRC
    [london-underground-pcb.kicad_pcb, london-underground-pcb.kicad_sch]
2025-02-23 Updated parts list from JLCPCB
    [london-underground-pcb.kicad_pcb, london-underground-pcb.kicad_sch]
2025-02-23 Added underground logo and preview image
    [london-underground-pcb.kicad_pcb]
2025-02-24 Added bird logo to the back panel
    [london-underground-pcb.kicad_pcb]
2025-02-24 As manufactured with JLCPCB 2024-Feb-24
    [bom.csv, designators.csv, london-underground-pcb.kicad_pcb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]
2025-11-26 2025-nov-25 - cleanup ready for review
    [london-underground-pcb.kicad_pcb, london-underground-pcb.kicad_sch, positions.csv]
2025-12-01 Fixed "unconnected items" in PCB viewer
    [london-underground-pcb.kicad_pcb]
2025-12-01 Fixed schematic errors
    [london-underground-pcb.kicad_sch]
2025-12-01 before trying to fix library issues
    [london-underground-pcb.kicad_pcb]
2025-12-01 submitted to JLCPCB 2025-Nov-30
    [bom.csv, designators.csv, london-underground-pcb.kicad_pcb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]
2026-01-21 testing script for LEDs
    [london-underground-pcb.kicad_pcb, station-names-to-led.csv]
2026-03-30 AI assisted update of all the LEDs offsets. There's still some work to be done here, but at least all the stations are all proper.
